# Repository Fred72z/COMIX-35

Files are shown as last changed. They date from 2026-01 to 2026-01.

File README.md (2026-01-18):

# COMIX-35 revision 1.2a

Le COMIX-35 est la réplique d'un ordinateur des années 1980, le COMX-35.
Il utilise le processeur COSMAC 1802 et dispose de 32K de mémoire vive et 3K de mémoir vidéo.

Cette version (1.2a) est une légère amélioration du COMIX-35 réalisé par "schlae".  
https://github.com/schlae/comix-35

Les améliorations sont : 
- le pcb est moins large (295mm) pour faciliter l'impression d'un boîtier
- les résistances ajustables sont verticales et plus petites
- le potentiomètre de volume est sur le côté G
- l'inter d'alimentation est vertical
- le connecteur d'extension est un modèle IDC 40 broches
- le circuit K7in est remplacé par un LM358 pour faciliter le chargement sans réglage de seuil.

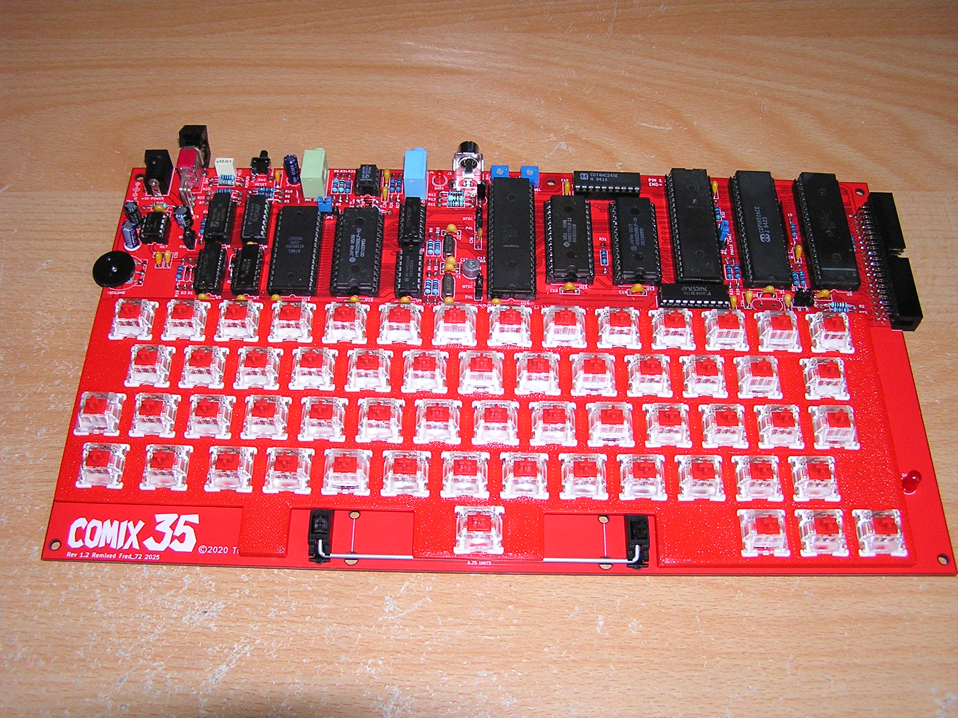
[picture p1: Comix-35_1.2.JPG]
Assemblage

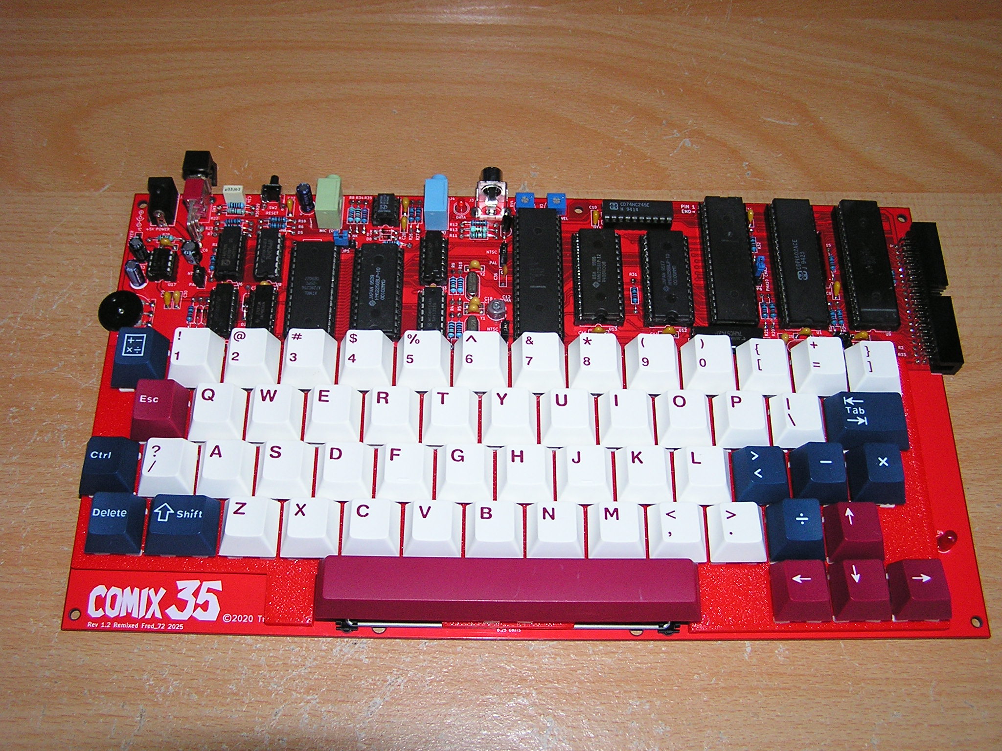
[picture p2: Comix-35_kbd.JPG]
Clavier


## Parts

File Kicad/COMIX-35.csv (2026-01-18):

Item | Qty | Reference(s) | Value | Digikey
1 | 21 | C1, C2, C3, C4, C5, C7, C8, C9, C10, C11, C14, C16, C17, C20, C21, C22, C25, C26, C28, C29, C30 | 0.1uF
2 | 1 | C6 | 100uF
3 | 1 | C12 | CHROMA | 2447-GKG30015-ND
4 | 6 | C13, C15, C18, C19, C23, C24 | 22pF
5 | 2 | C27, C32 | 47nF
7 | 2 | C31, C35 | 10uF
9 | 1 | C33 | 220uF
10 | 1 | C34 | 0.33uF
11 | 1 | C36 | 120pF
12 | 6 | D1, D2, D3, D5, D7, D8 | 1N4148
13 | 1 | D4 | POWER | Led D6mm
14 | 1 | D6 | DATA | Led D3mm
15 | 1 | J1 | Barrel_Jack | 5,5x2,1mm
16 | 1 | J2 | EXPANSION | IDC40 90°
17 | 1 | J3 | VIDEO | RCA PCB
18 | 1 | J4 | EAR | SJ1-353XN | Bleu
19 | 1 | J5 | Speaker
20 | 1 | J6 | MIC | SJ1-353XN | Vert
25 | 1 | M1 | Stabilisateur ‘ ‘ | 6u ou 7u
26 | 1 | Q1 | 2N3904
27 | 15 | R1, R3, R6, R14, R15, R16, R18, R19, R20, R21, R22, R26, R27, R31, R32 | 10K
28 | 2 | R2, R34 | 100K
29 | 3 | R4, R9, R23 | 1M
30 | 4 | R5, R10, R25, R29 | 1K
31 | 2 | R7, R33 | 2K2
 | 1 | R8 | 4K7
31 | 1 | R12 | 220
32 | 2 | R11, R28 | 10
33 | 1 | R13 | 75
34 | 1 | R17 | 10M
35 | 1 | R24 | 100K
36 | 1 | R30 | 100
 | 1 | R35 | 22K
37 | 1 | RN1 | 10K x 8 | SIP9
38 | 1 | RV2 | 10K | Pot plat 16x2 | Réglage volume
39 | 2 | RV3, RV4 | 10K | 3339P
40 | 1 | SW1 | POWER | T8020L
41 | 1 | SW2 | RESET | Tactile 9mm 90°
42 | 58 | SW3-SW60 |  | Cherry/Gateron
43 | 1 | U1 | CDP1802ACE
44 | 1 | U2 | 74HC574
45 | 2 | U3, U5 | 74HC74
46 | 1 | U4 | 74HCU04
47 | 1 | U6 | 74HC10
48 | 1 | U7 | 74HC86
49 | 1 | U8 | 74HC14
50 | 1 | U9 | CDP1871
51 | 1 | U10 | CDP1869
52 | 1 | U11 | 74HC245
53 | 3 | U12, U13, U16 | AS6C62256
54 | 1 | U14 | CDP1870
55 | 1 | U15 | 28C256
56 | 1 | U17 | LM386
56 | 1 | U18 | LM358
57 | 1 | Y1 | 17.738MHz
58 | 1 | Y2 | 11.2896MHz

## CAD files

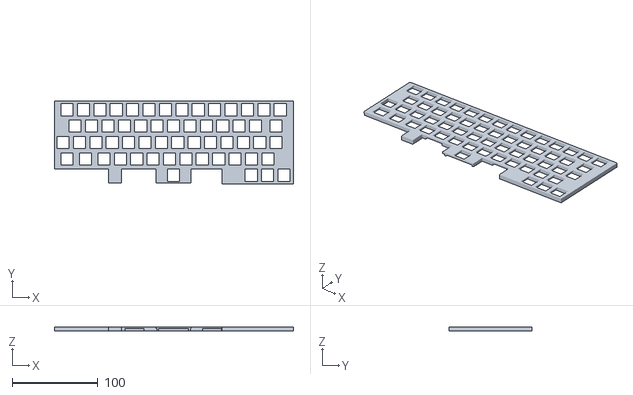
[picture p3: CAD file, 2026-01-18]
KBD/plaque_kbd.stl
278.0 x 96.0 x 5.00

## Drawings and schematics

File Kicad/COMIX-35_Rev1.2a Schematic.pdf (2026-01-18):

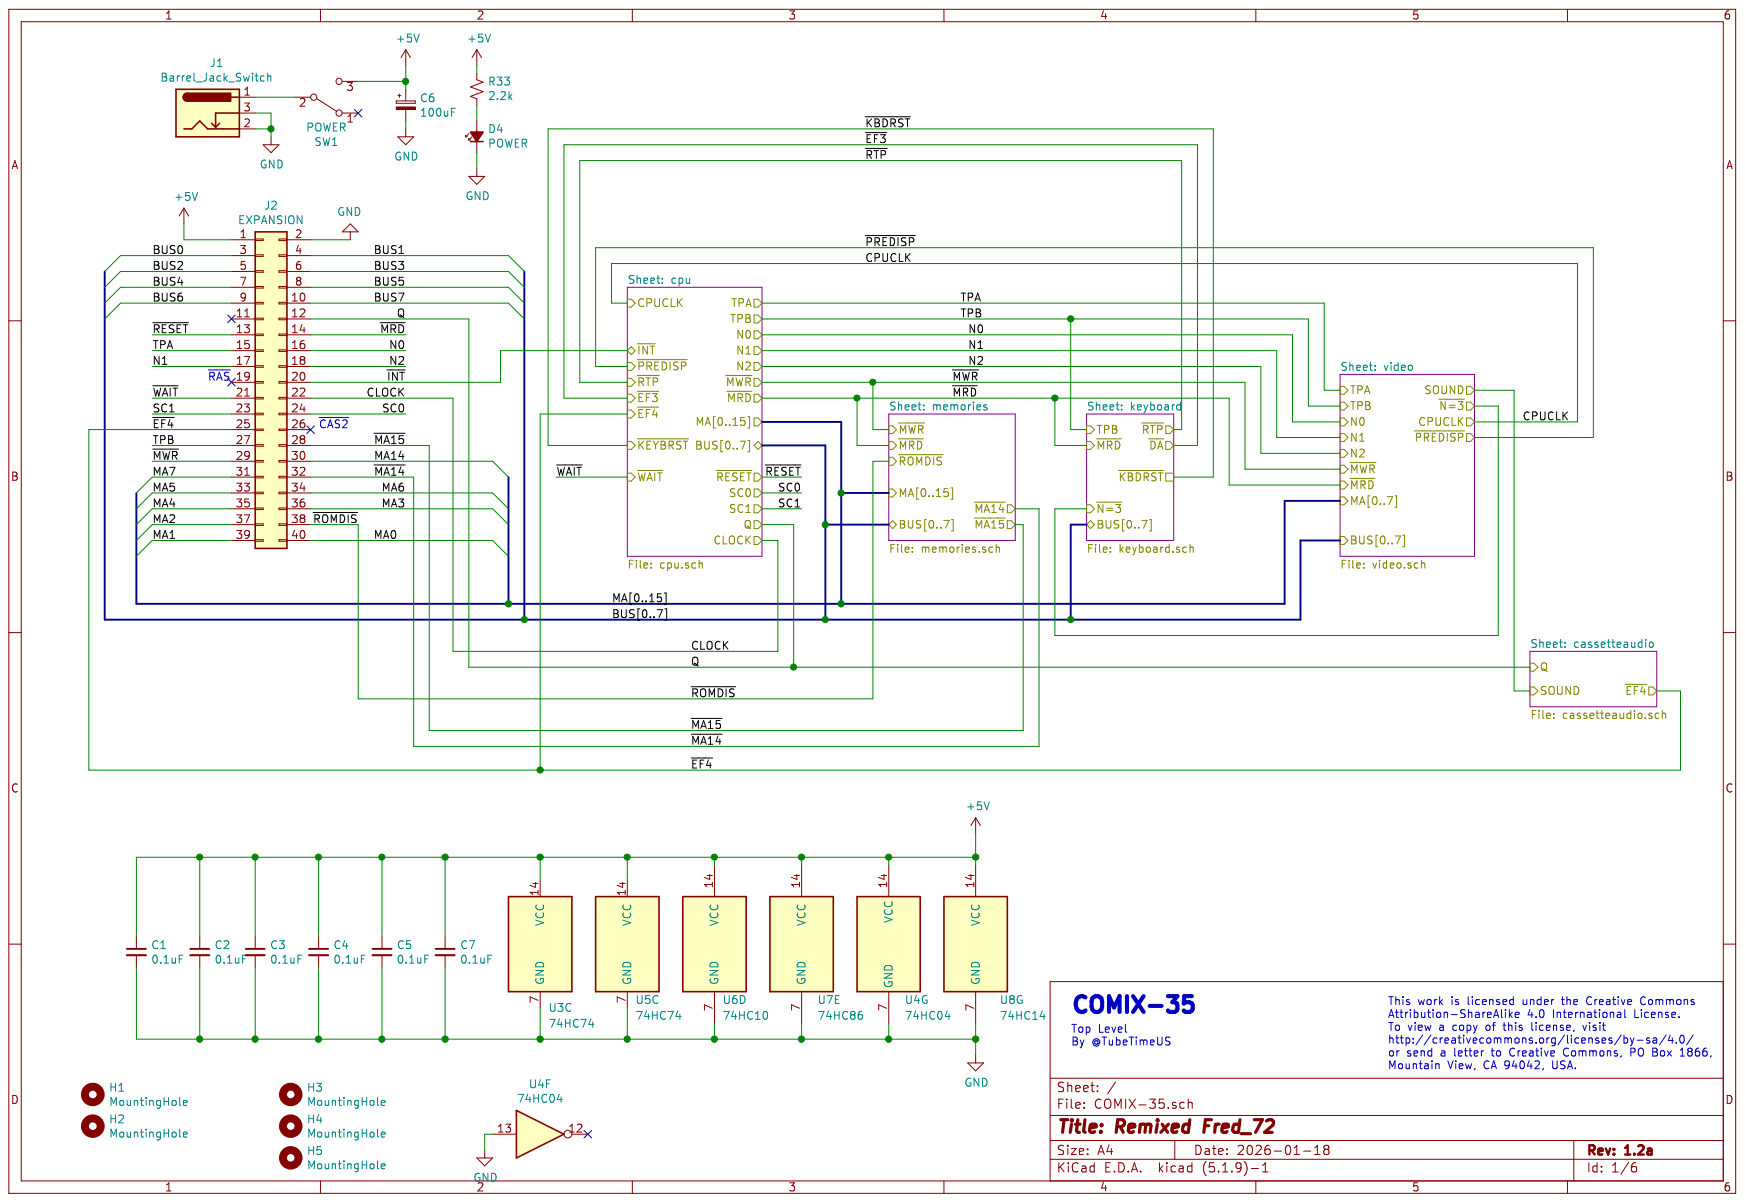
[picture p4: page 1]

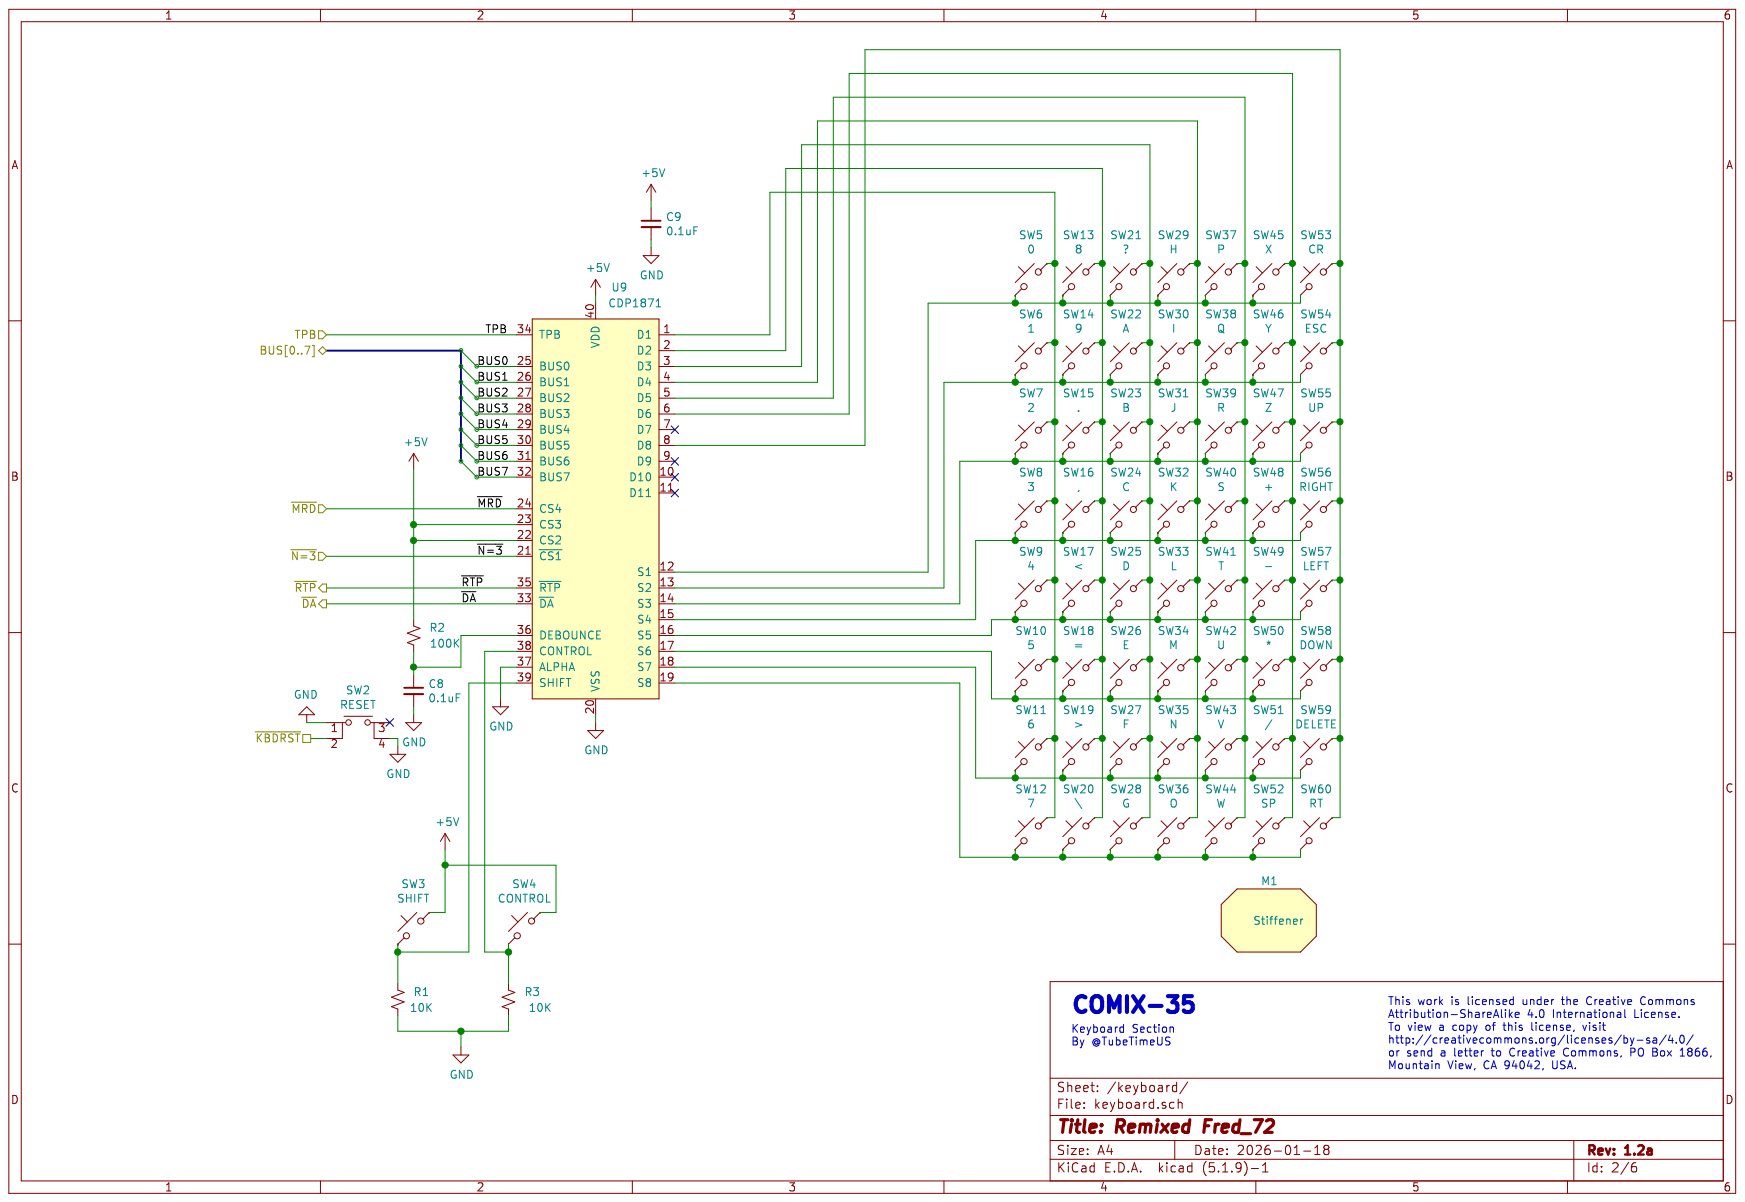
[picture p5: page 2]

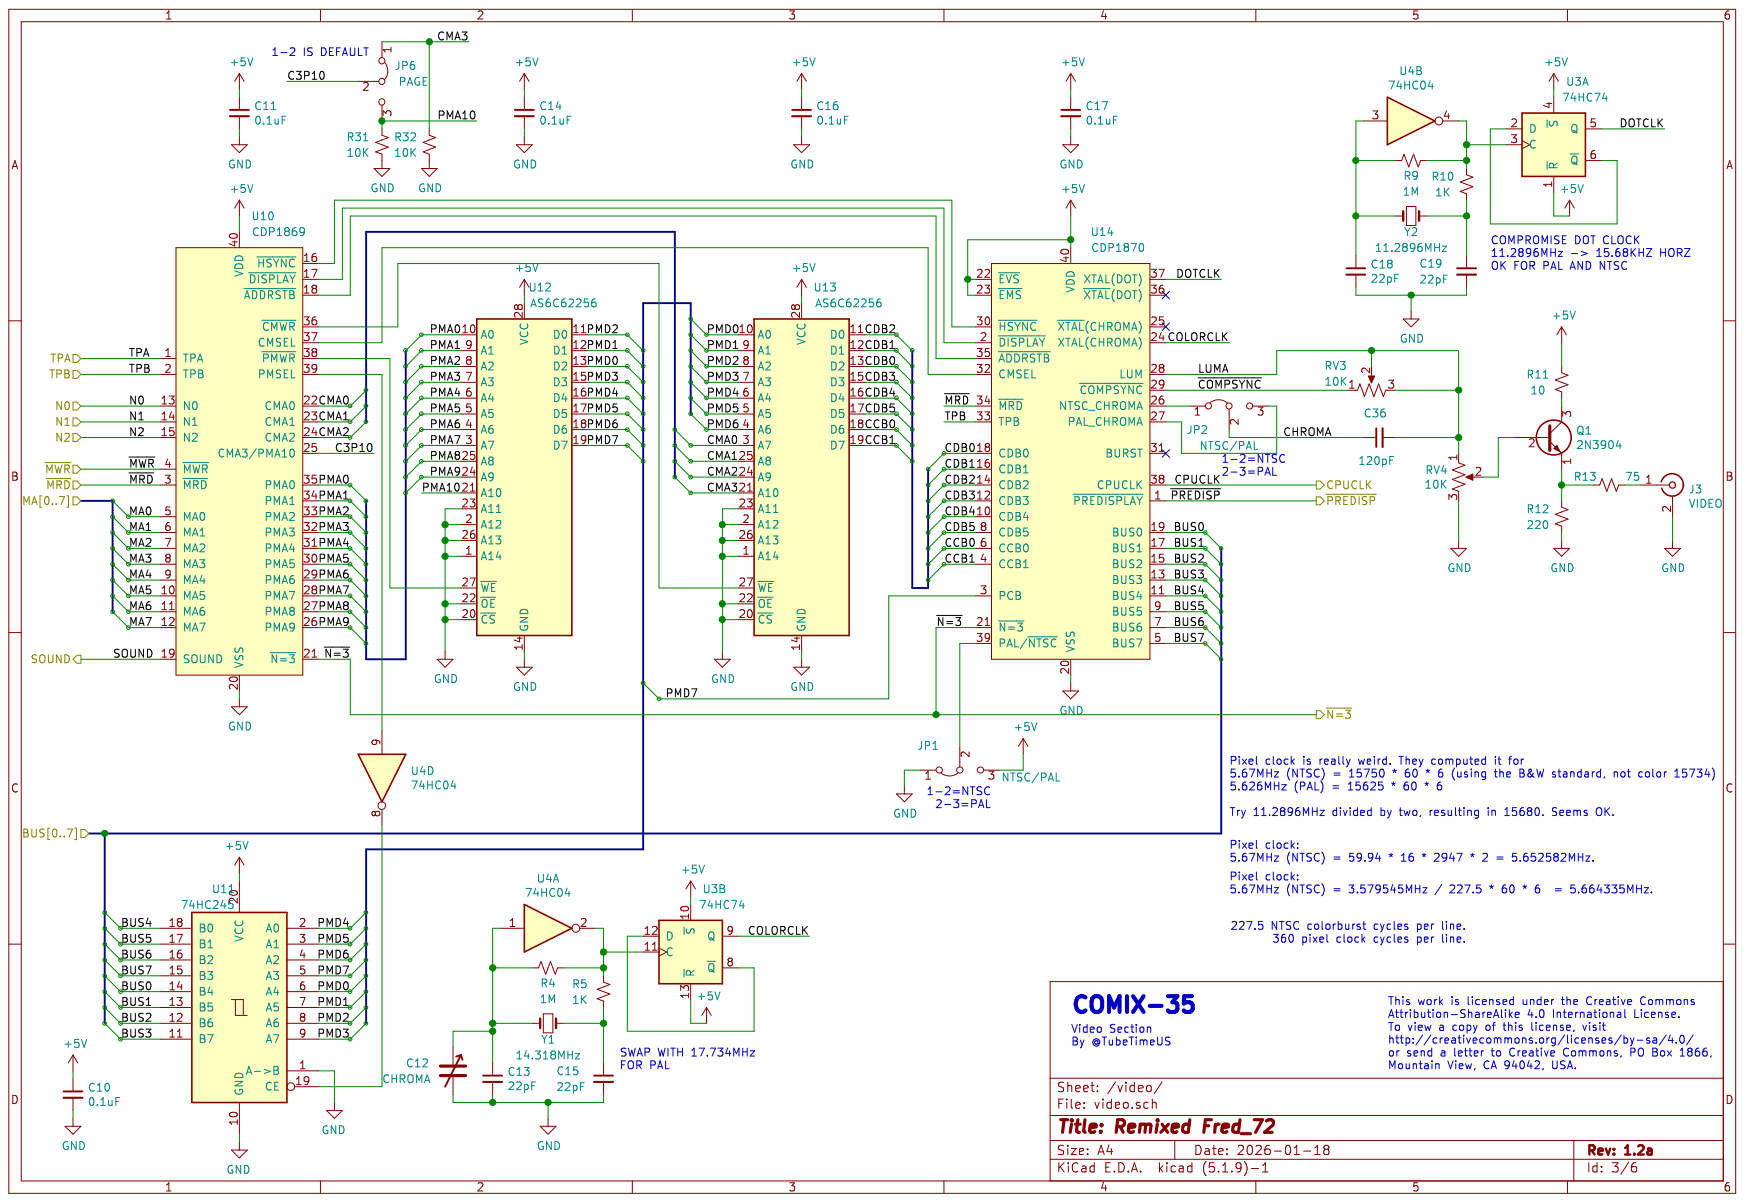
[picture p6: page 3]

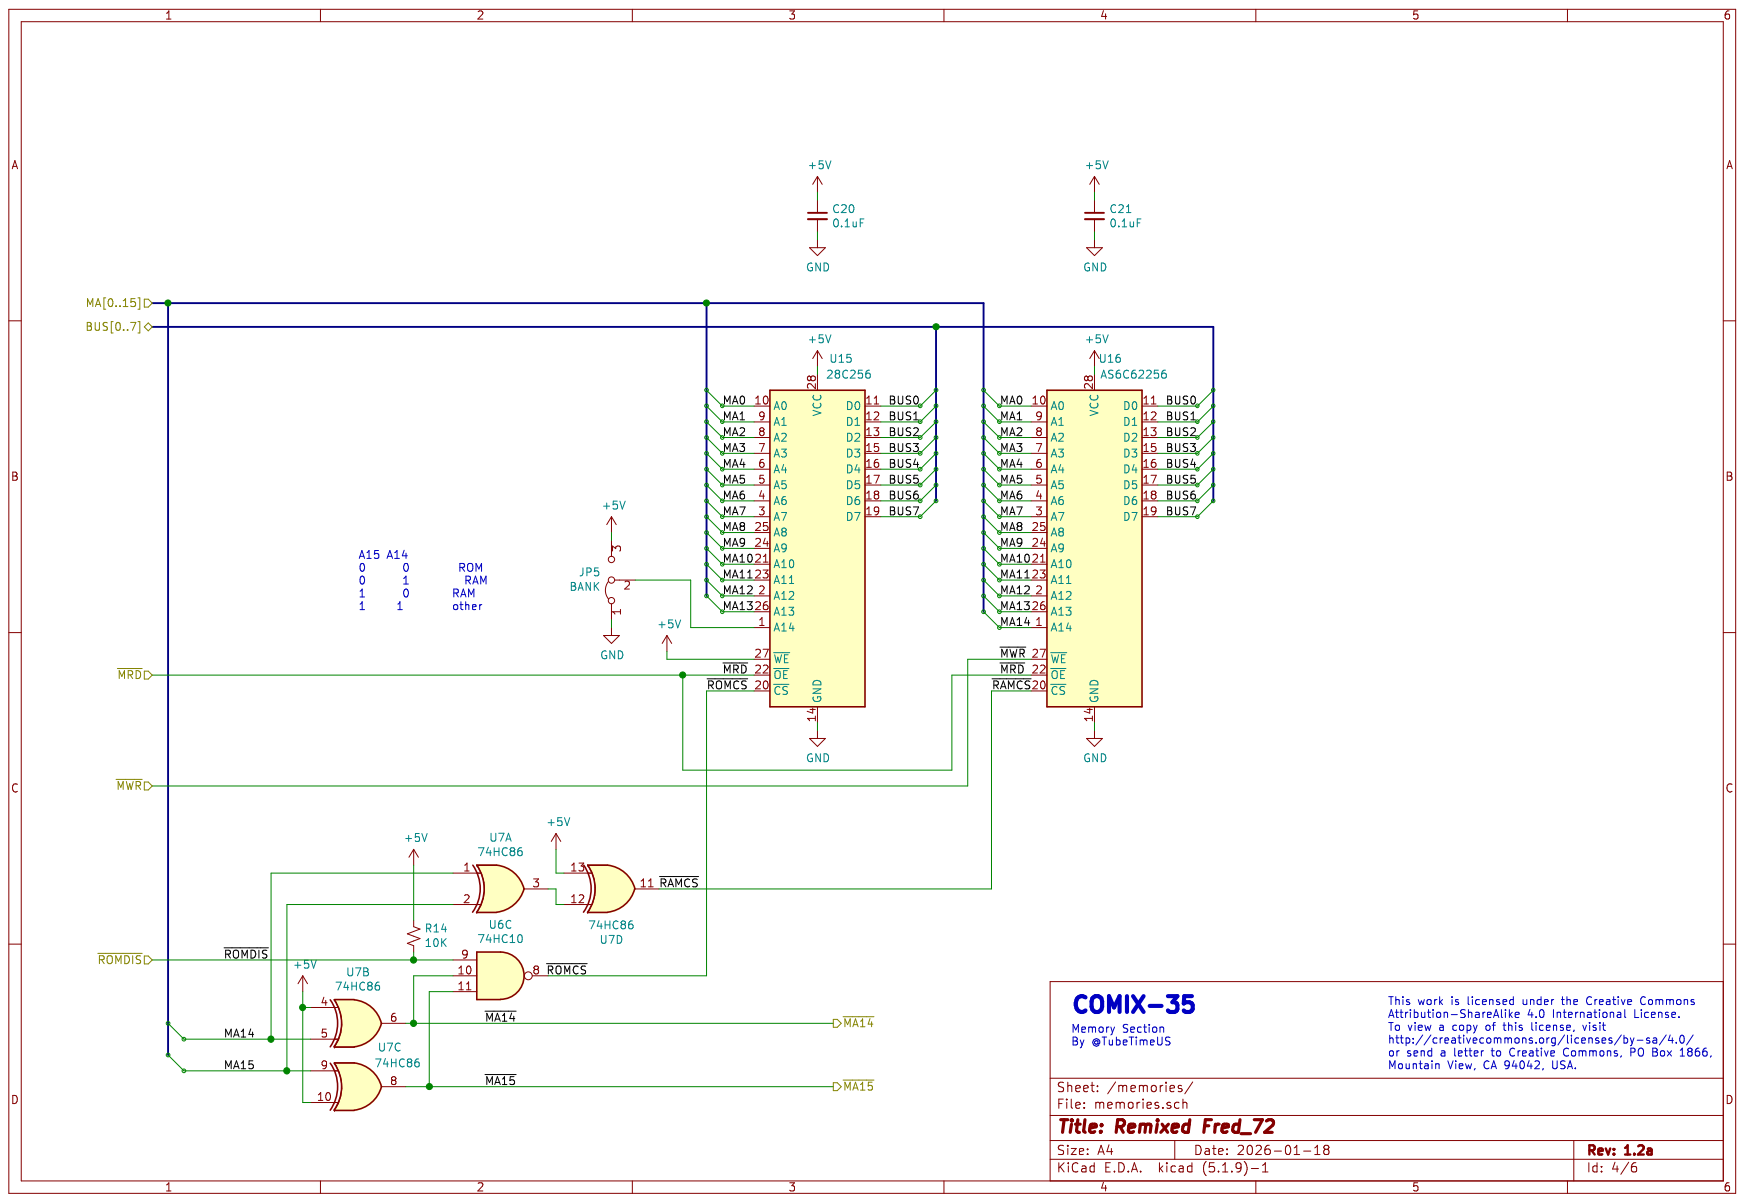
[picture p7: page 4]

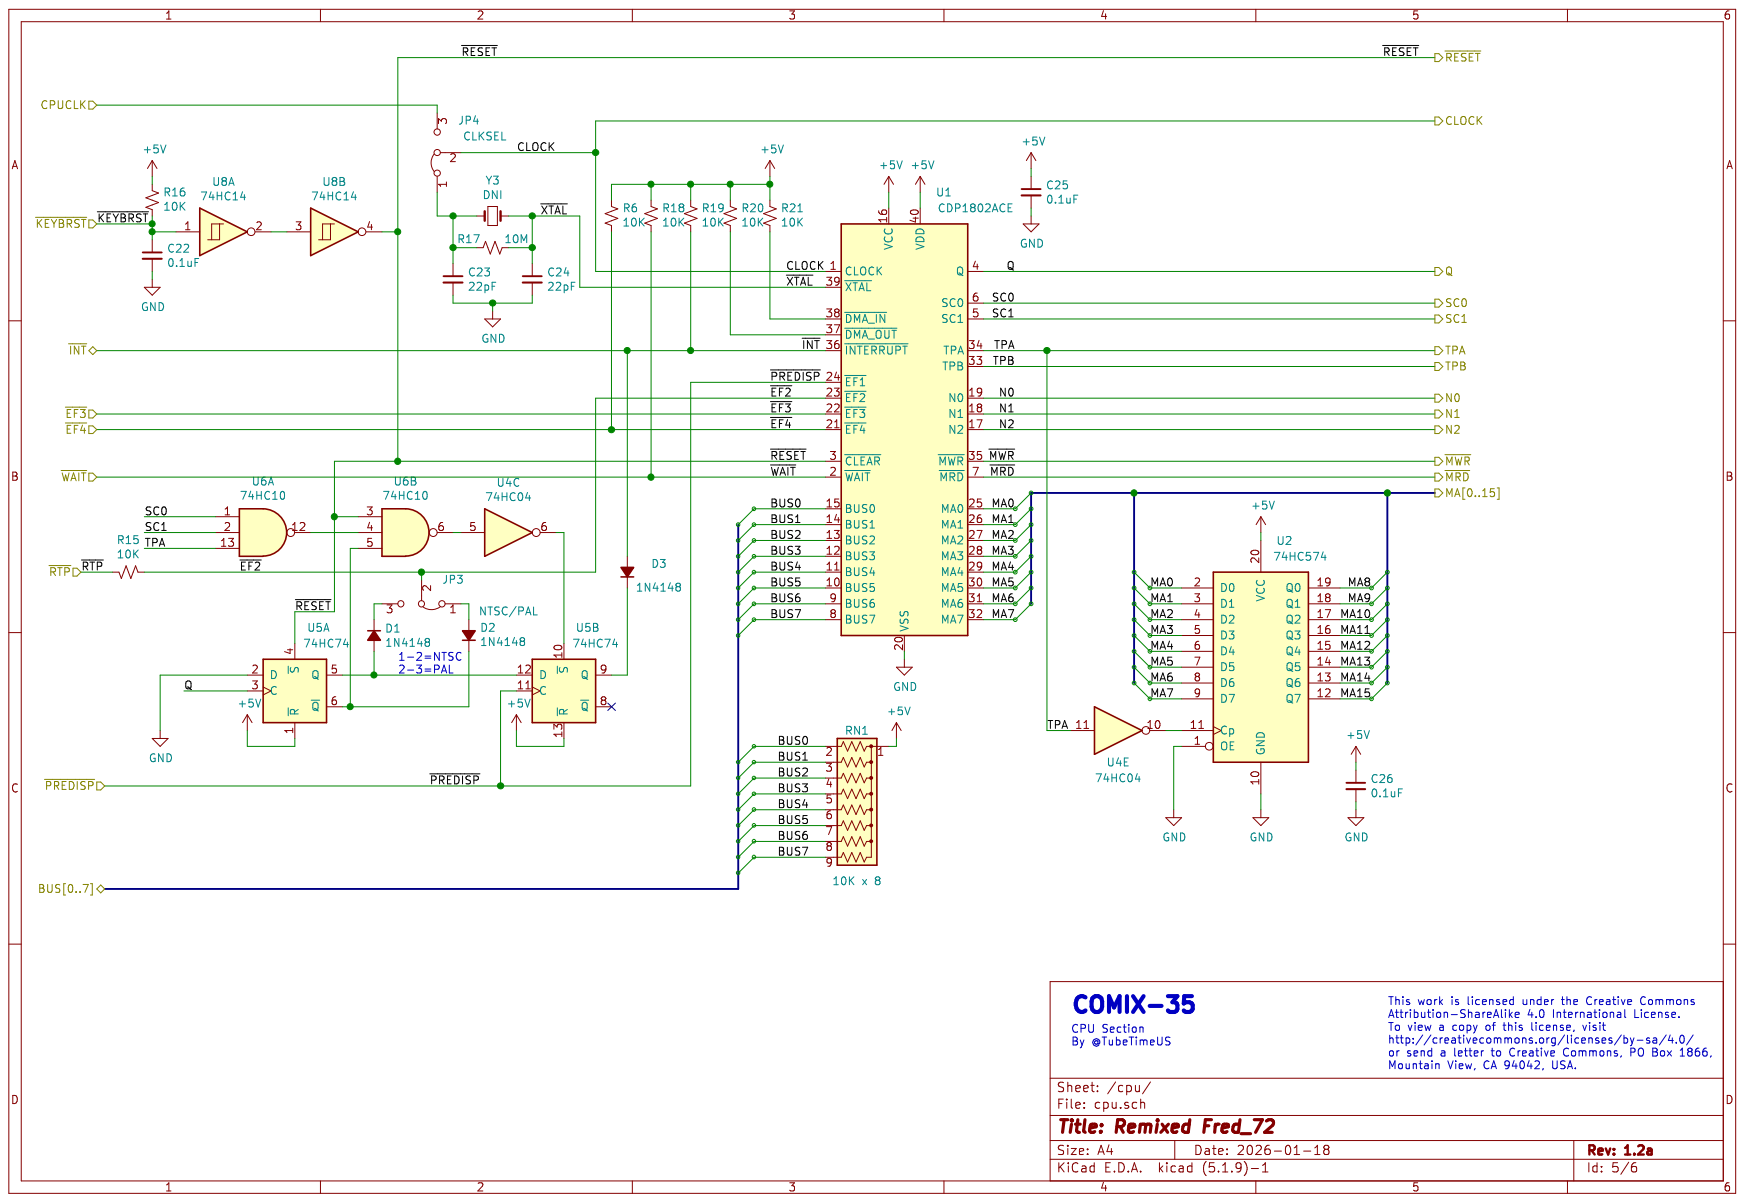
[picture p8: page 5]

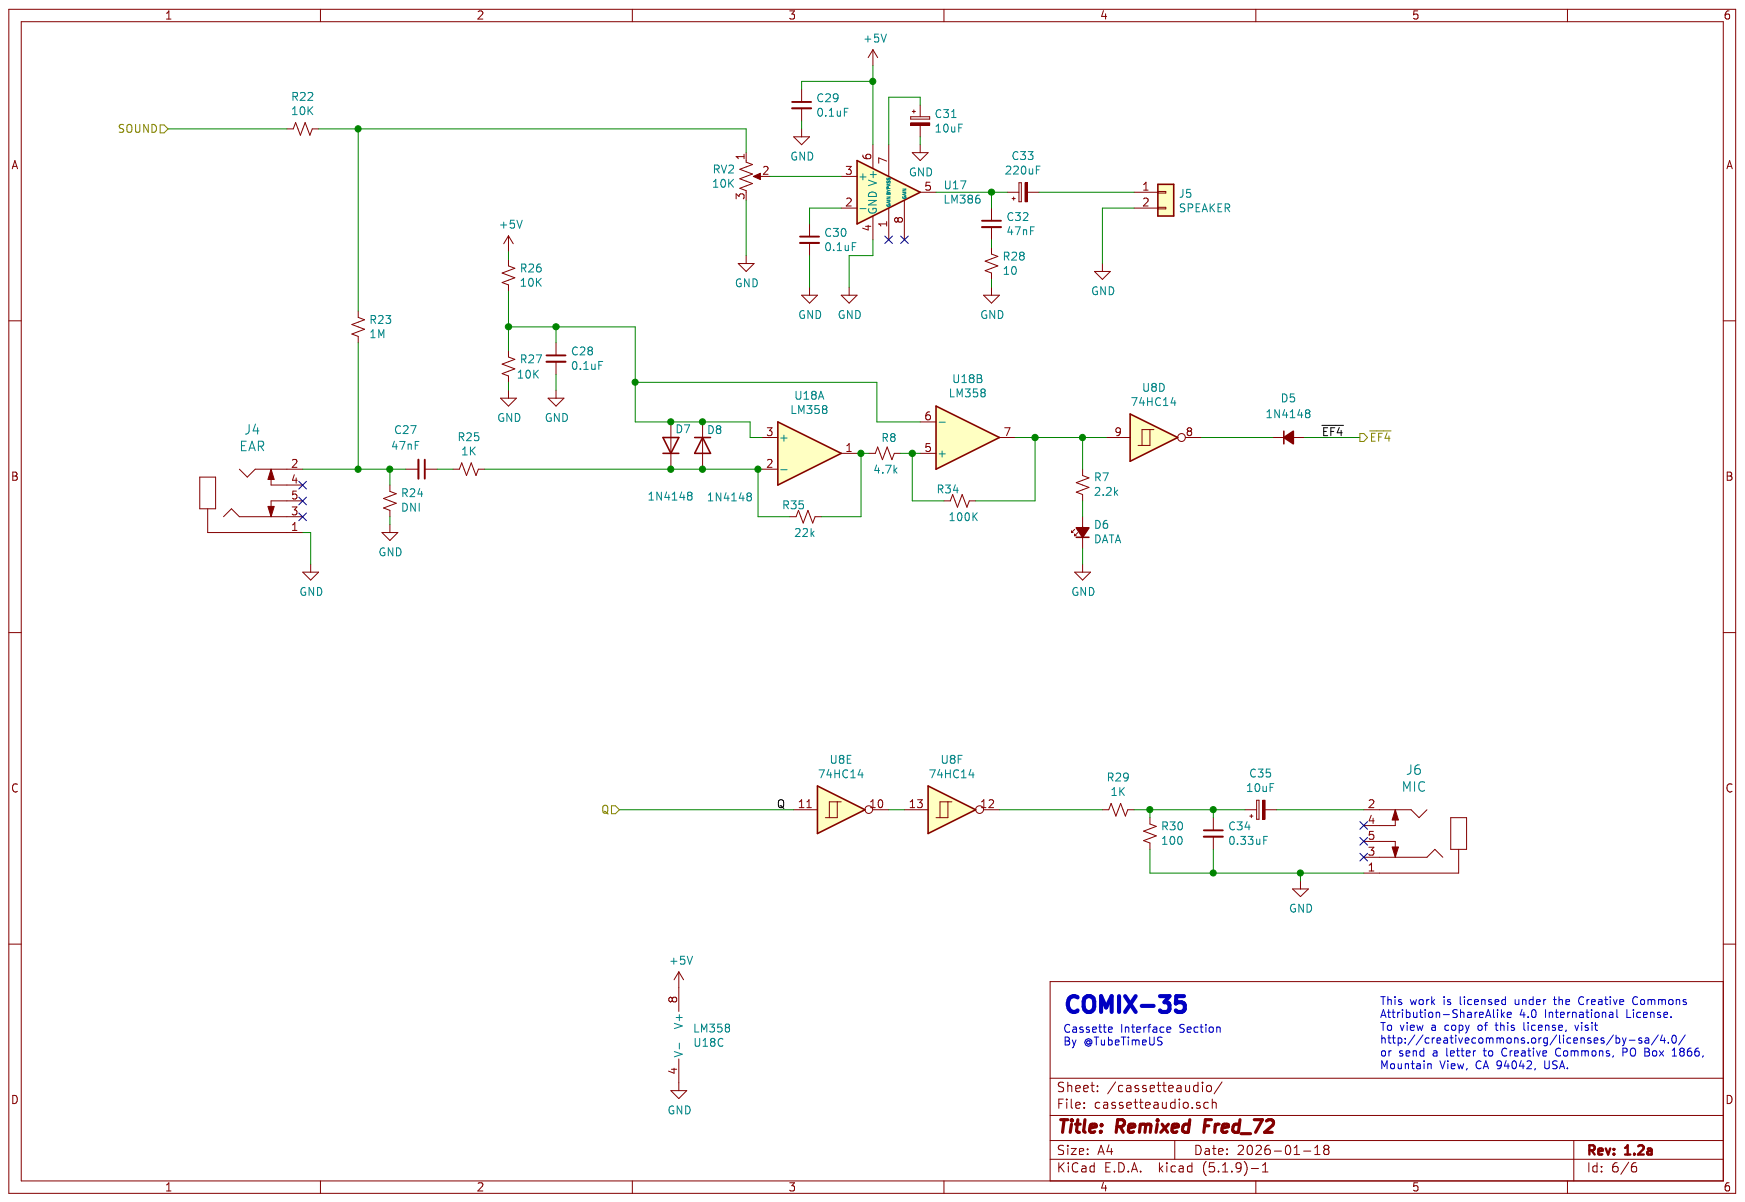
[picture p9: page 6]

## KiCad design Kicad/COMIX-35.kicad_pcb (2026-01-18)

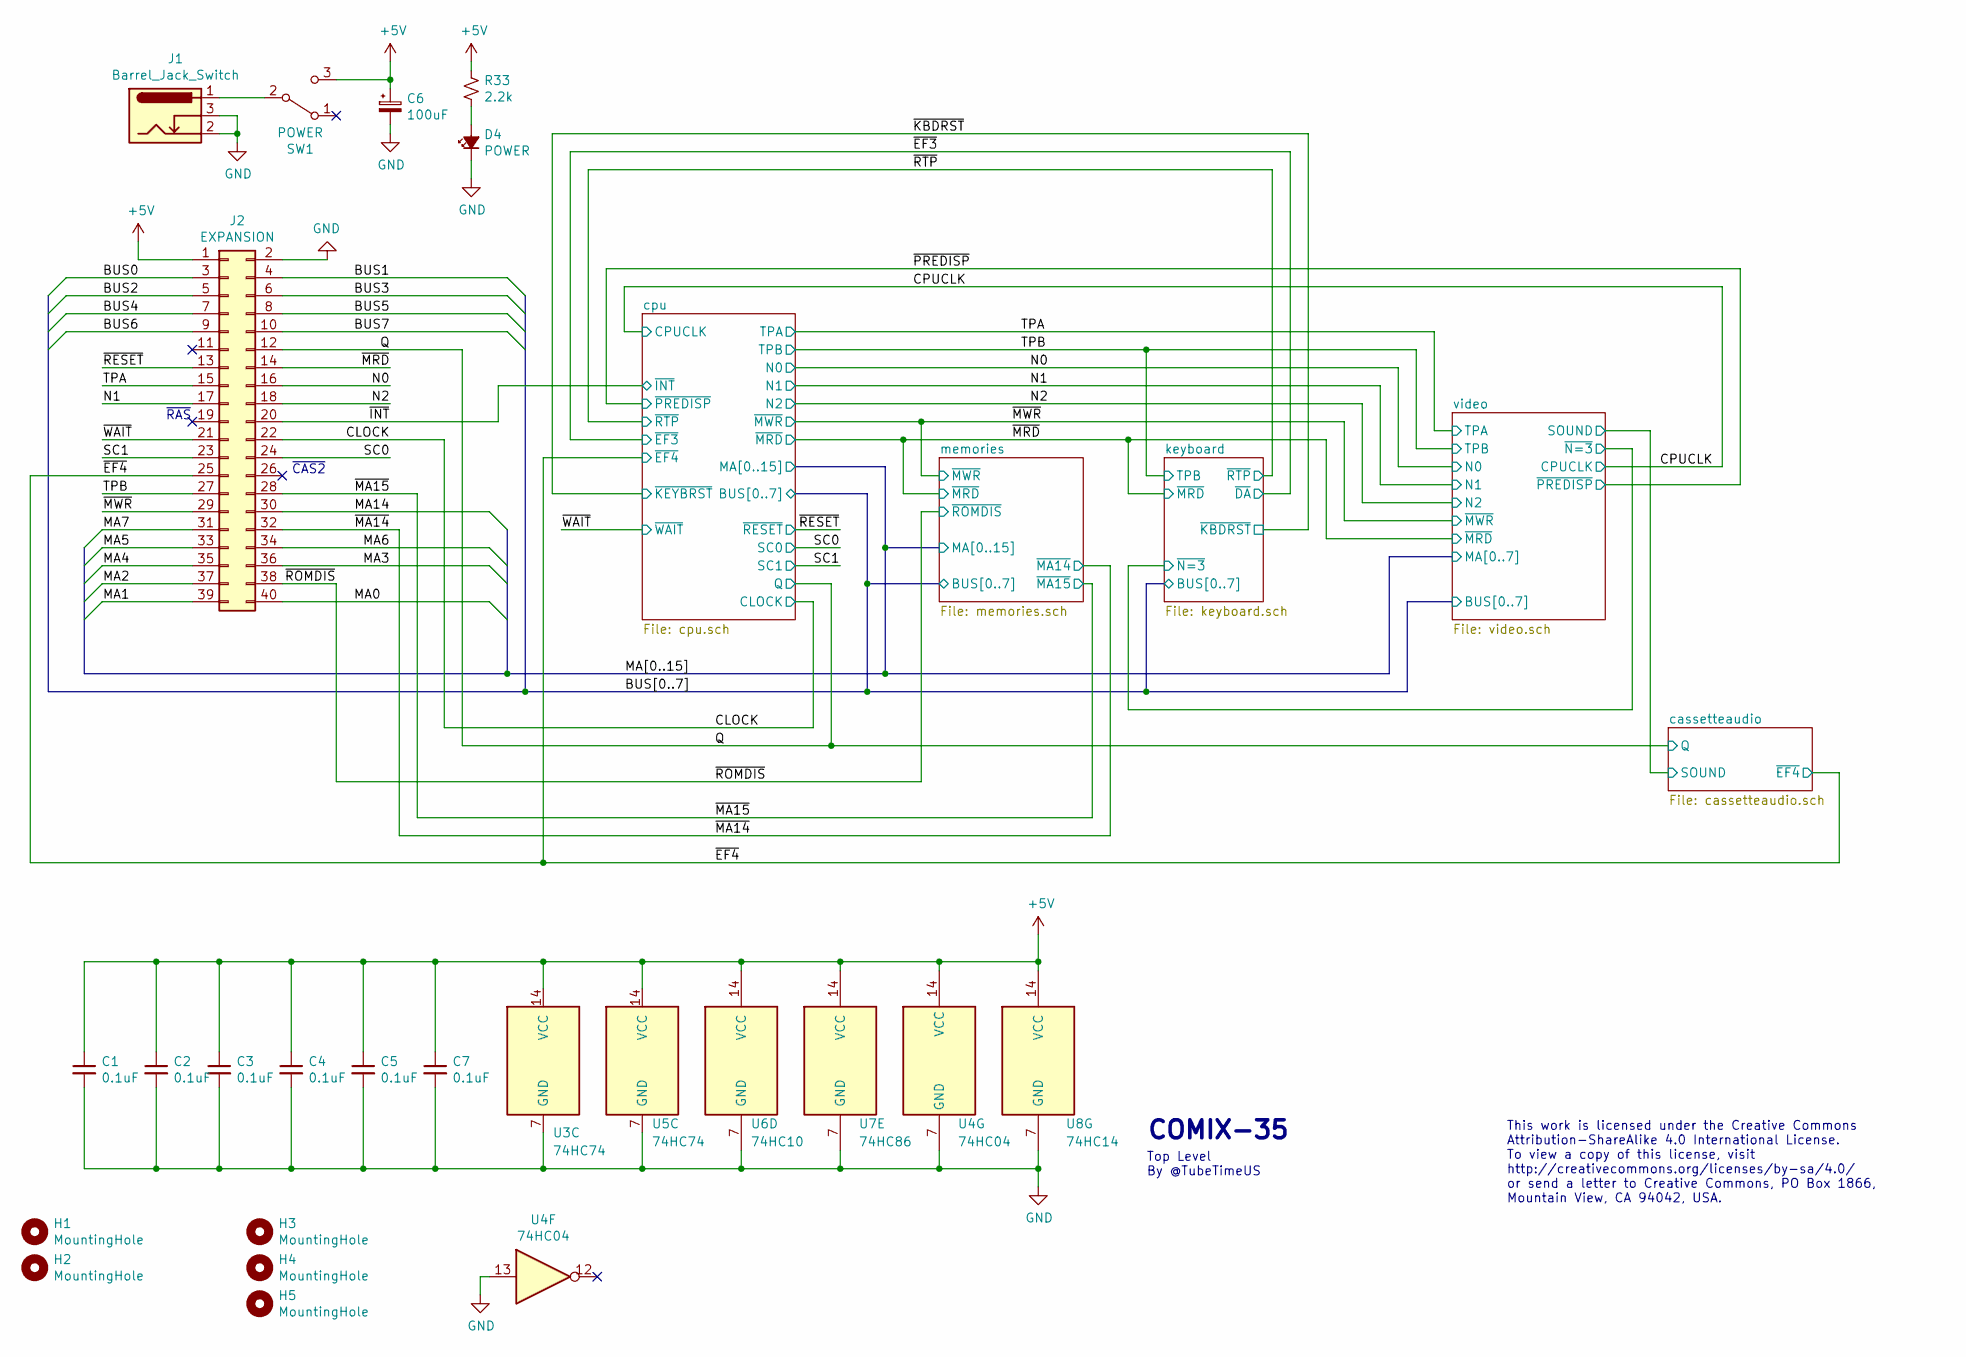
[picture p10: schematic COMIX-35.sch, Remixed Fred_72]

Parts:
C1, C2, C3, C4, C5, C7: 0.1uF; CAPAC200; Mouser 581-SA105E104M
C6: 100uF; CAPAE200P500X1100; Mouser 667-ECA-1CM101I
D4: POWER; LED_D5.0mm; Mouser 859-LTL-4213
H1, H2, H3, H4, H5: MountingHole; MountingHole_3.2mm_M3_DIN965
J1: Barrel_Jack_Switch; CUI_PJ-002B; Mouser 490-PJ-002B
J2: EXPANSION; IDC-Header_2x20_P2.54mm_Horizontal
R33: 2.2k; RESA500; Mouser 603-CFR-25JR-52220R
SW1: POWER; T8020L; Mouser 633-CS12ANW03
U3, U5: 74HC74; DIP-14_W7.62mm; Mouser 595-SN74HC74N
U4: 74HC04; DIP-14_W7.62mm; Mouser 595-SN74HCU04N
U6: 74HC10; DIP-14_W7.62mm; Mouser 595-SN74HC10N
U7: 74HC86; DIP-14_W7.62mm; Mouser 595-SN74HC86N
U8: 74HC14; DIP-14_W7.62mm; Mouser 595-SN74HC14N

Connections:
+5V: C1.1, C2.1, C3.1, C4.1, C5.1, C6.1, C7.1, J2.1, R33.2, SW1.3 (C), U3.14 (VCC), U4.14 (VCC), U5.14 (VCC), U6.14 (VCC), U7.14 (VCC), U8.14 (VCC); also elsewhere on the board
/BUS0: J2.3; also elsewhere on the board
/BUS1: J2.4; also elsewhere on the board
/BUS2: J2.5; also elsewhere on the board
/BUS3: J2.6; also elsewhere on the board
/BUS4: J2.7; also elsewhere on the board
/BUS5: J2.8; also elsewhere on the board
/BUS6: J2.9; also elsewhere on the board
/BUS7: J2.10; also elsewhere on the board
/CLOCK: J2.22; also elsewhere on the board
/MA0: J2.40; also elsewhere on the board
/MA1: J2.39; also elsewhere on the board
/MA2: J2.37; also elsewhere on the board
/MA3: J2.36; also elsewhere on the board
/MA4: J2.35; also elsewhere on the board
/MA5: J2.33; also elsewhere on the board
/MA6: J2.34; also elsewhere on the board
/MA7: J2.31; also elsewhere on the board
/MA14: J2.30; also elsewhere on the board
/N0: J2.16; also elsewhere on the board
/N1: J2.17; also elsewhere on the board
/N2: J2.18; also elsewhere on the board
/Q: J2.12; also elsewhere on the board
/SC0: J2.24; also elsewhere on the board
/SC1: J2.23; also elsewhere on the board
/TPA: J2.15; also elsewhere on the board
/TPB: J2.27; also elsewhere on the board
/~EF4: J2.25; also elsewhere on the board
/~INT: J2.20; also elsewhere on the board
/~MA14: J2.32; also elsewhere on the board
/~MA15: J2.28; also elsewhere on the board
/~MRD: J2.14; also elsewhere on the board
/~MWR: J2.29; also elsewhere on the board
/~RESET: J2.13; also elsewhere on the board
/~ROMDIS: J2.38; also elsewhere on the board
/~WAIT: J2.21; also elsewhere on the board
GND: C1.2, C2.2, C3.2, C4.2, C5.2, C6.2, C7.2, D4.1 (K), J1.2, J1.3, J2.2, U3.7 (GND), U4.7 (GND), U4.13, U5.7 (GND), U6.7 (GND), U7.7 (GND), U8.7 (GND); also elsewhere on the board
unnamed: D4.2 (A), R33.1
unnamed: J1.1, SW1.2 (B)

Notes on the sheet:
~RAS
~CAS2
This work is licensed under the Creative Commons Attribution-ShareAlike 4.0 International License. To view a copy of this license, visit http://creativecommons.org/licenses/by-sa/4.0/ or send a letter to Creative Commons, PO Box 1866, Mountain View, CA 94042, USA.
COMIX-35
Top Level By @TubeTimeUS

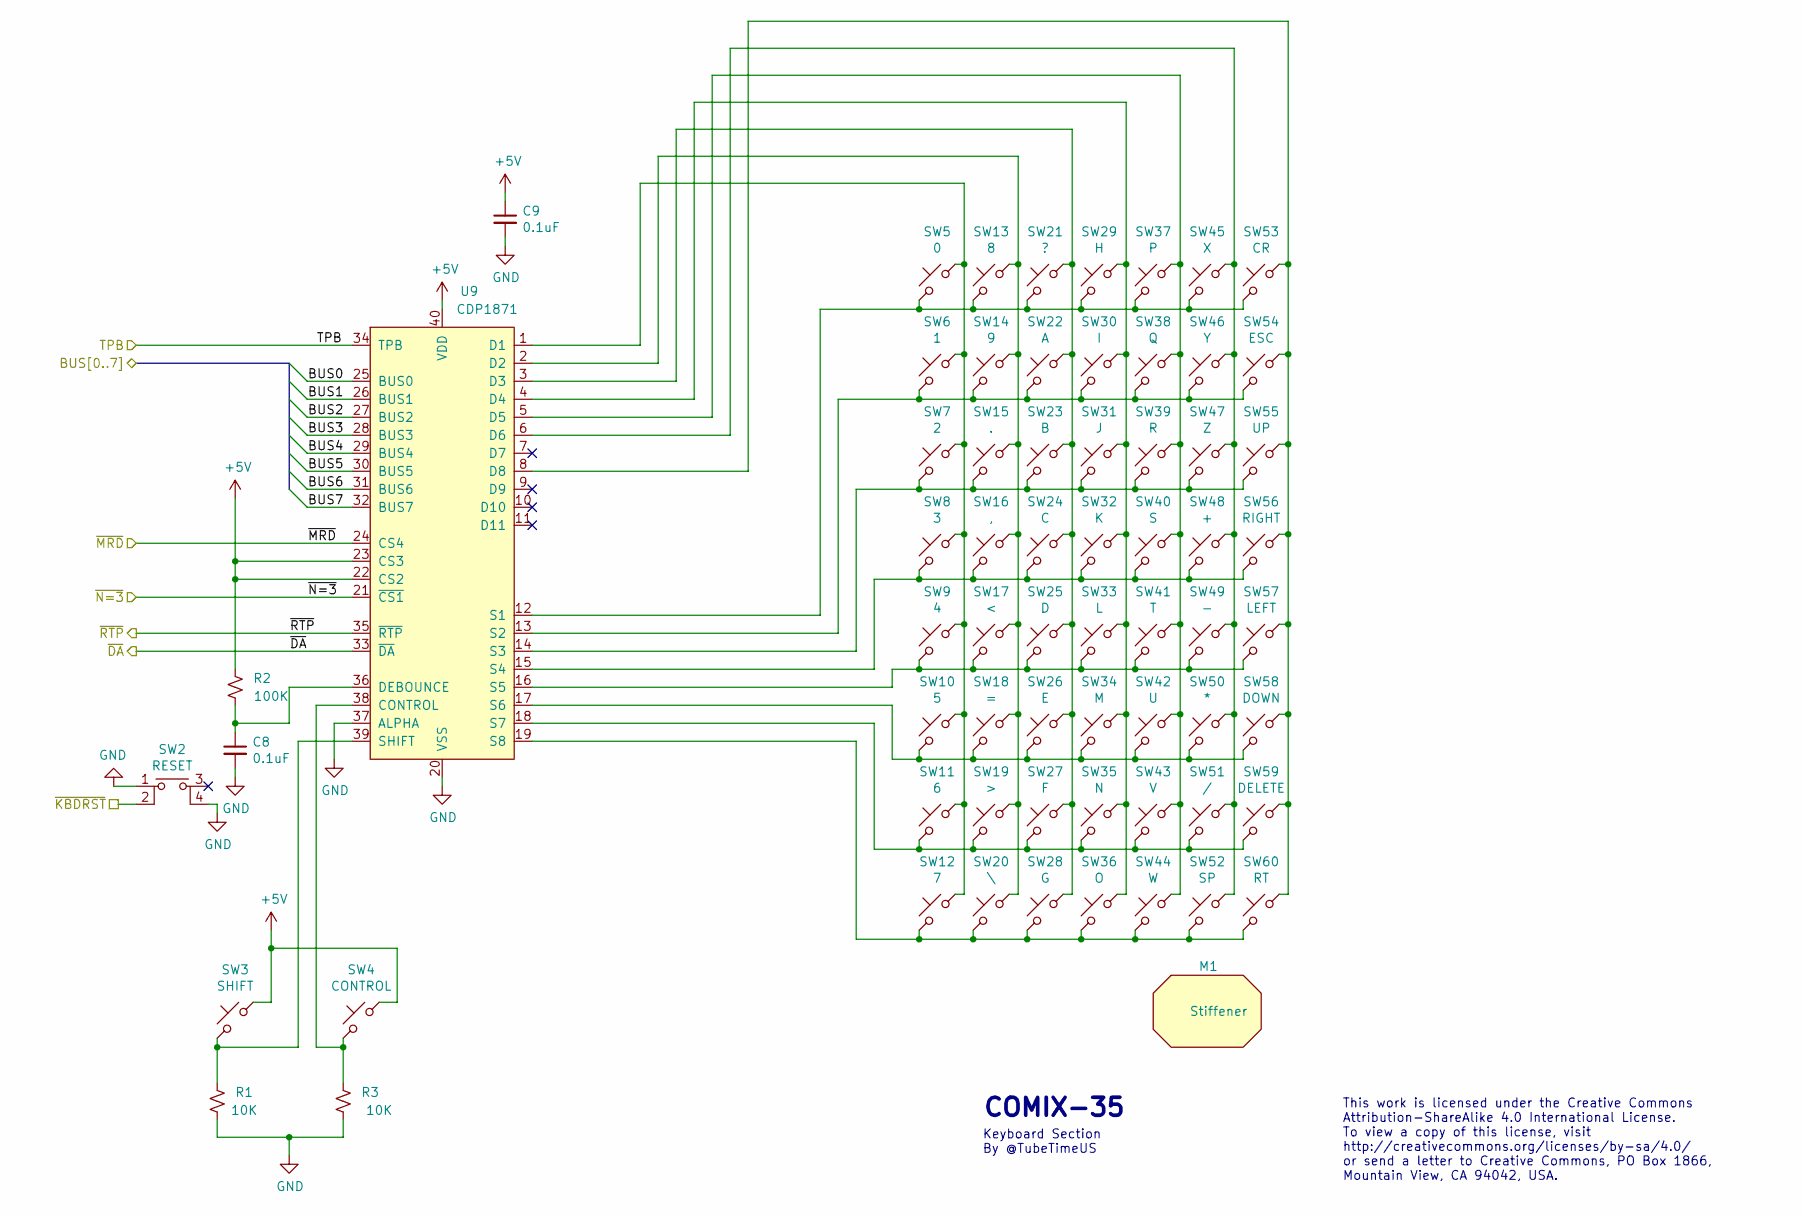
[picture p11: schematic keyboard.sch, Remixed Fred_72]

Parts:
C8, C9: 0.1uF; CAPAC200; Mouser 581-SA105E104M
M1: Stiffener; CHERRY_ST2; Mouser 540-0G990743
R1, R3: 10K; RESA500; Mouser 603-CFR-25JB-52-10K
R2: 100K; RESA500; Mouser 603-CFR-25JB-52-100K
SW2: RESET; SW_Tactile_SPST_Angled_PTS645Vx58-2LFS; Mouser 612-TL1105B
SW3: SHIFT; CHERRY_MX_125; Mouser 540-MX1A-11NW
SW4: CONTROL; CHERRY_MX; Mouser 540-MX1A-11NW
SW5: 0; CHERRY_MX; Mouser 540-MX1A-11NW
SW6: 1; CHERRY_MX; Mouser 540-MX1A-11NW
SW7: 2; CHERRY_MX; Mouser 540-MX1A-11NW
SW8: 3; CHERRY_MX; Mouser 540-MX1A-11NW
SW9: 4; CHERRY_MX; Mouser 540-MX1A-11NW
SW10: 5; CHERRY_MX; Mouser 540-MX1A-11NW
SW11: 6; CHERRY_MX; Mouser 540-MX1A-11NW
SW12: 7; CHERRY_MX; Mouser 540-MX1A-11NW
SW13: 8; CHERRY_MX; Mouser 540-MX1A-11NW
SW14: 9; CHERRY_MX; Mouser 540-MX1A-11NW
SW15: .; CHERRY_MX; Mouser 540-MX1A-11NW
SW16: ,; CHERRY_MX; Mouser 540-MX1A-11NW
SW17: <; CHERRY_MX; Mouser 540-MX1A-11NW
SW18: =; CHERRY_MX; Mouser 540-MX1A-11NW
SW19: >; CHERRY_MX; Mouser 540-MX1A-11NW
SW20: \\; CHERRY_MX; Mouser 540-MX1A-11NW
SW21: ?; CHERRY_MX; Mouser 540-MX1A-11NW
SW22: A; CHERRY_MX; Mouser 540-MX1A-11NW
SW23: B; CHERRY_MX; Mouser 540-MX1A-11NW
SW24: C; CHERRY_MX; Mouser 540-MX1A-11NW
SW25: D; CHERRY_MX; Mouser 540-MX1A-11NW
SW26: E; CHERRY_MX; Mouser 540-MX1A-11NW
SW27: F; CHERRY_MX; Mouser 540-MX1A-11NW
SW28: G; CHERRY_MX; Mouser 540-MX1A-11NW
SW29: H; CHERRY_MX; Mouser 540-MX1A-11NW
SW30: I; CHERRY_MX; Mouser 540-MX1A-11NW
SW31: J; CHERRY_MX; Mouser 540-MX1A-11NW
SW32: K; CHERRY_MX; Mouser 540-MX1A-11NW
SW33: L; CHERRY_MX; Mouser 540-MX1A-11NW
SW34: M; CHERRY_MX; Mouser 540-MX1A-11NW
SW35: N; CHERRY_MX; Mouser 540-MX1A-11NW
SW36: O; CHERRY_MX; Mouser 540-MX1A-11NW
SW37: P; CHERRY_MX; Mouser 540-MX1A-11NW
SW38: Q; CHERRY_MX; Mouser 540-MX1A-11NW
SW39: R; CHERRY_MX; Mouser 540-MX1A-11NW
SW40: S; CHERRY_MX; Mouser 540-MX1A-11NW
SW41: T; CHERRY_MX; Mouser 540-MX1A-11NW
SW42: U; CHERRY_MX; Mouser 540-MX1A-11NW
SW43: V; CHERRY_MX; Mouser 540-MX1A-11NW
SW44: W; CHERRY_MX; Mouser 540-MX1A-11NW
SW45: X; CHERRY_MX; Mouser 540-MX1A-11NW
SW46: Y; CHERRY_MX; Mouser 540-MX1A-11NW
SW47: Z; CHERRY_MX; Mouser 540-MX1A-11NW
SW48: +; CHERRY_MX; Mouser 540-MX1A-11NW
SW49: -; CHERRY_MX; Mouser 540-MX1A-11NW
SW50: *; CHERRY_MX; Mouser 540-MX1A-11NW
SW51: /; CHERRY_MX; Mouser 540-MX1A-11NW
SW52: SP; CHERRY_MX_625; Mouser 540-MX1A-11NW
SW53: CR; CHERRY_MX_150; Mouser 540-MX1A-11NW
SW54: ESC; CHERRY_MX; Mouser 540-MX1A-11NW
SW55: UP; CHERRY_MX; Mouser 540-MX1A-11NW
SW56: RIGHT; CHERRY_MX; Mouser 540-MX1A-11NW
SW57: LEFT; CHERRY_MX; Mouser 540-MX1A-11NW
SW58: DOWN; CHERRY_MX; Mouser 540-MX1A-11NW
SW59: DELETE; CHERRY_MX; Mouser 540-MX1A-11NW
SW60: RT; CHERRY_MX; Mouser 540-MX1A-11NW
U9: CDP1871; DIP-40_W15.24mm

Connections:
+5V: C9.1, R2.1, SW3.1, SW4.1, U9.22 (CS2), U9.23 (CS3), U9.40 (VDD); also elsewhere on the board
/BUS0: U9.25 (BUS0); also elsewhere on the board
/BUS1: U9.26 (BUS1); also elsewhere on the board
/BUS2: U9.27 (BUS2); also elsewhere on the board
/BUS3: U9.28 (BUS3); also elsewhere on the board
/BUS4: U9.29 (BUS4); also elsewhere on the board
/BUS5: U9.30 (BUS5); also elsewhere on the board
/BUS6: U9.31 (BUS6); also elsewhere on the board
/BUS7: U9.32 (BUS7); also elsewhere on the board
/TPB: U9.34 (TPB); also elsewhere on the board
/keyboard/~N=3: U9.21 (~CS1); also elsewhere on the board
/~EF3: U9.33 (~DA); also elsewhere on the board
/~KBDRST: SW2.2; also elsewhere on the board
/~MRD: U9.24 (CS4); also elsewhere on the board
/~RTP: U9.35 (~RTP); also elsewhere on the board
GND: C8.2, C9.2, R1.2, R3.2, SW2.1, SW2.4, U9.20 (VSS), U9.37 (ALPHA); also elsewhere on the board
unnamed: C8.1, R2.2, U9.36 (DEBOUNCE)
unnamed: R1.1, SW3.2, U9.39 (SHIFT)
unnamed: R3.1, SW4.2, U9.38 (CONTROL)
unnamed: SW5.1, SW6.1, SW7.1, SW8.1, SW9.1, SW10.1, SW11.1, SW12.1, U9.1 (D1)
unnamed: SW10.2, SW18.2, SW26.2, SW34.2, SW42.2, SW50.2, SW58.2, U9.17 (S6)
unnamed: SW11.2, SW19.2, SW27.2, SW35.2, SW43.2, SW51.2, SW59.2, U9.18 (S7)
unnamed: SW12.2, SW20.2, SW28.2, SW36.2, SW44.2, SW52.2, SW60.2, U9.19 (S8)
unnamed: SW13.1, SW14.1, SW15.1, SW16.1, SW17.1, SW18.1, SW19.1, SW20.1, U9.2 (D2)
unnamed: SW5.2, SW13.2, SW21.2, SW29.2, SW37.2, SW45.2, SW53.2, U9.12 (S1)
unnamed: SW6.2, SW14.2, SW22.2, SW30.2, SW38.2, SW46.2, SW54.2, U9.13 (S2)
unnamed: SW7.2, SW15.2, SW23.2, SW31.2, SW39.2, SW47.2, SW55.2, U9.14 (S3)
unnamed: SW8.2, SW16.2, SW24.2, SW32.2, SW40.2, SW48.2, SW56.2, U9.15 (S4)
unnamed: SW9.2, SW17.2, SW25.2, SW33.2, SW41.2, SW49.2, SW57.2, U9.16 (S5)
unnamed: SW21.1, SW22.1, SW23.1, SW24.1, SW25.1, SW26.1, SW27.1, SW28.1, U9.3 (D3)
unnamed: SW29.1, SW30.1, SW31.1, SW32.1, SW33.1, SW34.1, SW35.1, SW36.1, U9.4 (D4)
unnamed: SW37.1, SW38.1, SW39.1, SW40.1, SW41.1, SW42.1, SW43.1, SW44.1, U9.5 (D5)
unnamed: SW45.1, SW46.1, SW47.1, SW48.1, SW49.1, SW50.1, SW51.1, SW52.1, U9.6 (D6)
unnamed: SW53.1, SW54.1, SW55.1, SW56.1, SW57.1, SW58.1, SW59.1, SW60.1, U9.8 (D8)

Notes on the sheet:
This work is licensed under the Creative Commons Attribution-ShareAlike 4.0 International License. To view a copy of this license, visit http://creativecommons.org/licenses/by-sa/4.0/ or send a letter to Creative Commons, PO Box 1866, Mountain View, CA 94042, USA.
COMIX-35
Keyboard Section By @TubeTimeUS

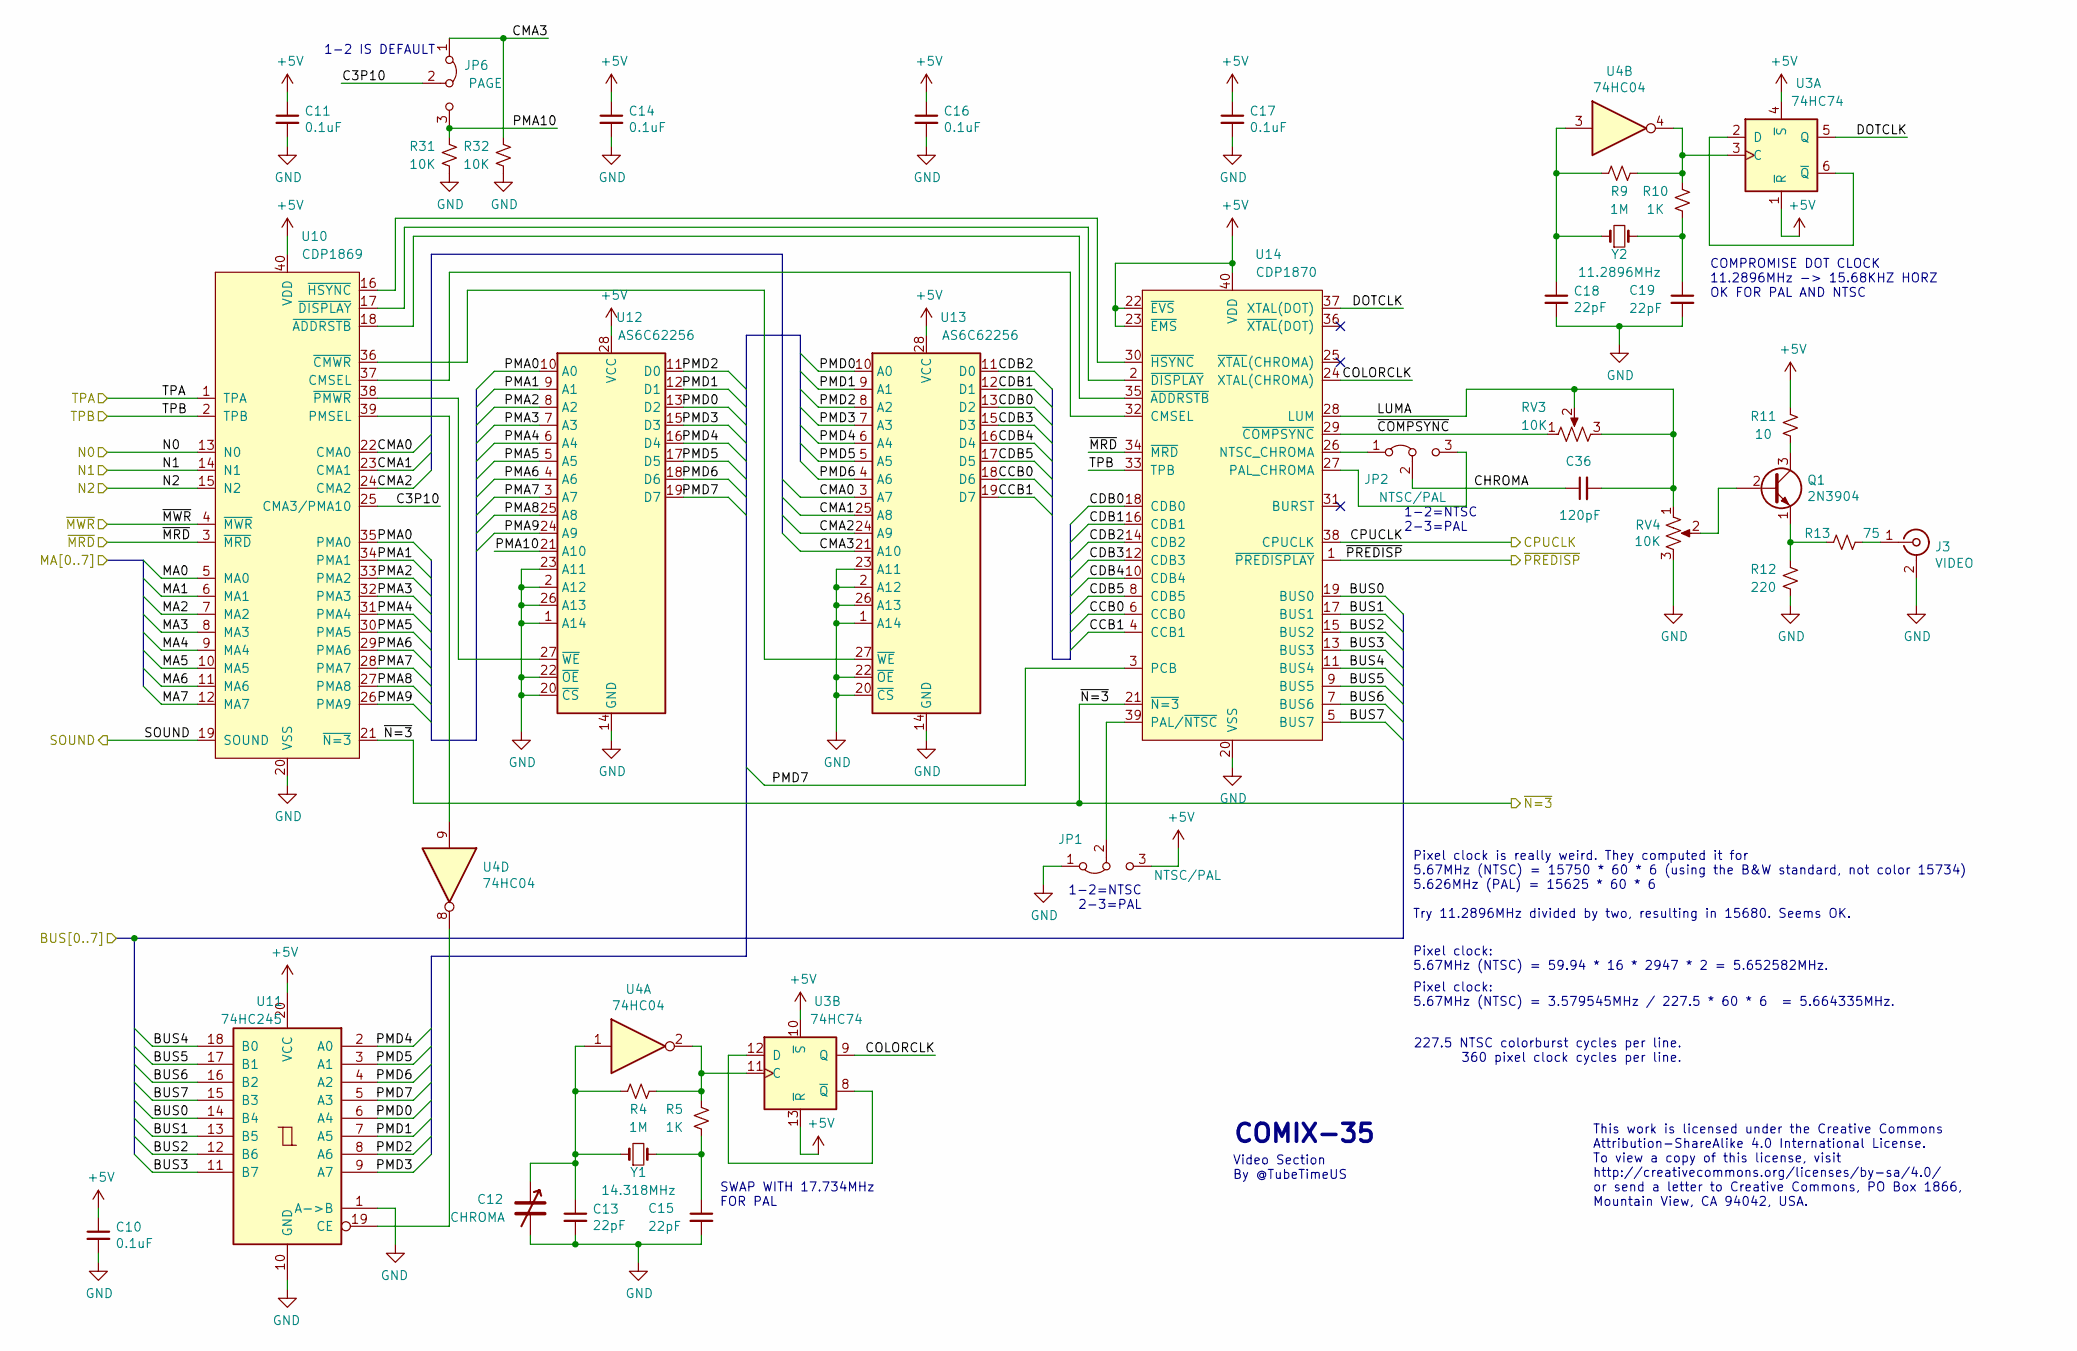
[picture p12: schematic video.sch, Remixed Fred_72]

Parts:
C10, C11, C14, C16, C17: 0.1uF; CAPAC200; Mouser 581-SA105E104M
C12: CHROMA; EW_GKG; Digikey 2447-GKG30015-ND
C13, C15, C18, C19: 22pF; CAPAC200; Mouser 810-FG28C0G2A220JNT0
C36: 120pF; CAPAC200; Mouser 810-FG28C0G1H121JNT6
J3: VIDEO; RCA_metal_Horizontal_L5mm; Mouser 161-0360-E
JP1, JP2: NTSC/PAL; Pin_Header_Straight_1x03_Pitch2.54mm
JP6: PAGE; Pin_Header_Straight_1x03_Pitch2.54mm
Q1: 2N3904; TO92-IL; Mouser 512-2N3904BU
R4, R9: 1M; RESA500; Mouser 603-CFR-25JR-521M
R5, R10: 1K; RESA500; Mouser 603-CFR-25JR-521K
R11: 10; RESA500; Mouser 603-CFR-25JR-5210R
R12: 220; RESA500; Mouser 603-CFR-25JR-52220R
R13: 75; RESA500; Mouser 603-CFR-25JR-5275R
R31, R32: 10K; RESA500; Mouser 603-CFR-25JB-52-10K
RV3, RV4: 10K; Potentiometer_Bourns_3339P_Vertical_HandSoldering; Mouser 531-PT10H-10K-S
U3: 74HC74; DIP-14_W7.62mm; Mouser 595-SN74HC74N
U4: 74HC04; DIP-14_W7.62mm; Mouser 595-SN74HC04N
U10: CDP1869; DIP-40_W15.24mm
U11: 74HC245; DIP-20_W7.62mm; Mouser 595-SN74HC245N
U12, U13: AS6C62256; DIP-28_W15.24mm; Mouser 913-AS6C62256-55PCN
U14: CDP1870; DIP-40_W15.24mm
Y1: 14.318MHz; Crystal_HC49-4H_Vertical; Mouser 815-ABL-14.31818B2
Y2: 11.2896MHz; Crystal_HC49-4H_Vertical; Mouser 815-ABL-11.2896-B4Y

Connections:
+5V: C10.1, C11.1, C14.1, C16.1, C17.1, JP1.3 (B), R11.1, U3.1 (~R), U3.4 (~S), U3.10 (~S), U3.13 (~R), U10.40 (VDD), U11.20 (VCC), U12.28 (VCC), U13.28 (VCC), U14.22 (~EVS), U14.23 (~EMS), U14.40 (VDD); also elsewhere on the board
/BUS0: U11.14 (B4), U14.19 (BUS0); also elsewhere on the board
/BUS1: U11.13 (B5), U14.17 (BUS1); also elsewhere on the board
/BUS2: U11.12 (B6), U14.15 (BUS2); also elsewhere on the board
/BUS3: U11.11 (B7), U14.13 (BUS3); also elsewhere on the board
/BUS4: U11.18 (B0), U14.11 (BUS4); also elsewhere on the board
/BUS5: U11.17 (B1), U14.9 (BUS5); also elsewhere on the board
/BUS6: U11.16 (B2), U14.7 (BUS6); also elsewhere on the board
/BUS7: U11.15 (B3), U14.5 (BUS7); also elsewhere on the board
/CPUCLK: U14.38 (CPUCLK); also elsewhere on the board
/MA0: U10.5 (MA0); also elsewhere on the board
/MA1: U10.6 (MA1); also elsewhere on the board
/MA2: U10.7 (MA2); also elsewhere on the board
/MA3: U10.8 (MA3); also elsewhere on the board
/MA4: U10.9 (MA4); also elsewhere on the board
/MA5: U10.10 (MA5); also elsewhere on the board
/MA6: U10.11 (MA6); also elsewhere on the board
/MA7: U10.12 (MA7); also elsewhere on the board
/N0: U10.13 (N0); also elsewhere on the board
/N1: U10.14 (N1); also elsewhere on the board
/N2: U10.15 (N2); also elsewhere on the board
/TPA: U10.1 (TPA); also elsewhere on the board
/TPB: U10.2 (TPB), U14.33 (TPB); also elsewhere on the board
/cassetteaudio/SOUND: U10.19 (SOUND); also elsewhere on the board
/keyboard/~N=3: U10.21 (~N=3), U14.21 (~N=3); also elsewhere on the board
/video/C3P10: JP6.2 (C), U10.25 (CMA3/PMA10)
/video/CCB0: U13.18 (D6), U14.6 (CCB0)
/video/CCB1: U13.19 (D7), U14.4 (CCB1)
/video/CDB0: U13.13 (D2), U14.18 (CDB0)
/video/CDB1: U13.12 (D1), U14.16 (CDB1)
/video/CDB2: U13.11 (D0), U14.14 (CDB2)
/video/CDB3: U13.15 (D3), U14.12 (CDB3)
/video/CDB4: U13.16 (D4), U14.10 (CDB4)
/video/CDB5: U13.17 (D5), U14.8 (CDB5)
/video/CHROMA: C36.1, JP2.2 (C)
/video/CMA0: U10.22 (CMA0), U13.3 (A7)
/video/CMA1: U10.23 (CMA1), U13.25 (A8)
/video/CMA2: U10.24 (CMA2), U13.24 (A9)
/video/CMA3: JP6.1 (A), R32.1, U13.21 (A10)
/video/COLORCLK: U3.9 (Q), U14.24 (XTAL(CHROMA))
/video/DOTCLK: U3.5 (Q), U14.37 (XTAL(DOT))
/video/LUMA: C36.2, RV3.2, RV3.3, RV4.1, U14.28 (LUM)
/video/PMA0: U10.35 (PMA0), U12.10 (A0)
/video/PMA1: U10.34 (PMA1), U12.9 (A1)
/video/PMA2: U10.33 (PMA2), U12.8 (A2)
/video/PMA3: U10.32 (PMA3), U12.7 (A3)
/video/PMA4: U10.31 (PMA4), U12.6 (A4)
/video/PMA5: U10.30 (PMA5), U12.5 (A5)
/video/PMA6: U10.29 (PMA6), U12.4 (A6)
/video/PMA7: U10.28 (PMA7), U12.3 (A7)
/video/PMA8: U10.27 (PMA8), U12.25 (A8)
/video/PMA9: U10.26 (PMA9), U12.24 (A9)
/video/PMA10: JP6.3 (B), R31.1, U12.21 (A10)
/video/PMD0: U11.6 (A4), U12.13 (D2), U13.10 (A0)
/video/PMD1: U11.7 (A5), U12.12 (D1), U13.9 (A1)
/video/PMD2: U11.8 (A6), U12.11 (D0), U13.8 (A2)
/video/PMD3: U11.9 (A7), U12.15 (D3), U13.7 (A3)
/video/PMD4: U11.2 (A0), U12.16 (D4), U13.6 (A4)
/video/PMD5: U11.3 (A1), U12.17 (D5), U13.5 (A5)
/video/PMD6: U11.4 (A2), U12.18 (D6), U13.4 (A6)
/video/PMD7: U11.5 (A3), U12.19 (D7), U14.3 (PCB)
/video/~COMPSYNC: RV3.1, U14.29 (~COMPSYNC)
/~MRD: U10.3 (~MRD), U14.34 (~MRD); also elsewhere on the board
/~MWR: U10.4 (~MWR); also elsewhere on the board
/~PREDISP: U14.1 (~PREDISPLAY); also elsewhere on the board
GND: C10.2, C11.2, C12.2, C13.2, C14.2, C15.2, C16.2, C17.2, C18.2, C19.2, J3.2 (Ext), JP1.1 (A), R12.2, R31.2, R32.2, RV4.3, U10.20 (VSS), U11.1 (A->B), U11.10 (GND), U12.1 (A14), U12.2 (A12), U12.14 (GND), U12.20 (~CS), U12.22 (~OE), U12.23 (A11), U12.26 (A13), U13.1 (A14), U13.2 (A12), U13.14 (GND), U13.20 (~CS), U13.22 (~OE), U13.23 (A11), U13.26 (A13), U14.20 (VSS); also elsewhere on the board
unnamed: C12.1, C13.1, R4.1, U4.1, Y1.1
unnamed: C15.1, R5.2, Y1.2
unnamed: C18.1, R9.1, U4.3, Y2.1
unnamed: C19.1, R10.2, Y2.2
unnamed: J3.1 (In), R13.2
unnamed: JP1.2 (C), U14.39 (PAL/~NTSC)
unnamed: JP2.1 (A), U14.26 (NTSC_CHROMA)
unnamed: JP2.3 (B), U14.27 (PAL_CHROMA)
unnamed: Q1.1 (E), R12.1, R13.1
unnamed: Q1.2 (B), RV4.2
unnamed: Q1.3 (C), R11.2
unnamed: R4.2, R5.1, U3.11 (C), U4.2
unnamed: R9.2, R10.1, U3.3 (C), U4.4
unnamed: U3.2 (D), U3.6 (~Q)
unnamed: U3.8 (~Q), U3.12 (D)
unnamed: U10.16 (~HSYNC), U14.30 (~HSYNC)
unnamed: U10.17 (~DISPLAY), U14.2 (~DISPLAY)
unnamed: U10.18 (~ADDRSTB), U14.35 (~ADDRSTB)
unnamed: U10.36 (~CMWR), U13.27 (~WE)
unnamed: U10.37 (CMSEL), U14.32 (CMSEL)
unnamed: U10.38 (~PMWR), U12.27 (~WE)
unnamed: U4.9, U10.39 (PMSEL)
unnamed: U4.8, U11.19 (CE)

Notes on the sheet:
COMPROMISE DOT CLOCK 11.2896MHz -> 15.68KHZ HORZ OK FOR PAL AND NTSC
SWAP WITH 17.734MHz FOR PAL
1-2=NTSC 2-3=PAL
Pixel clock is really weird. They computed it for 5.67MHz (NTSC) = 15750 * 60 * 6 (using the B&W standard, not color 15734) 5.626MHz (PAL) = 15625 * 60 * 6 Try 11.2896MHz divided by two, resulting in 15680. Seems OK.
Pixel clock: 5.67MHz (NTSC) = 59.94 * 16 * 2947 * 2 = 5.652582MHz.
Pixel clock: 5.67MHz (NTSC) = 3.579545MHz / 227.5 * 60 * 6 = 5.664335MHz.
227.5 NTSC colorburst cycles per line. 360 pixel clock cycles per line.
1-2 IS DEFAULT
This work is licensed under the Creative Commons Attribution-ShareAlike 4.0 International License. To view a copy of this license, visit http://creativecommons.org/licenses/by-sa/4.0/ or send a letter to Creative Commons, PO Box 1866, Mountain View, CA 94042, USA.
COMIX-35
Video Section By @TubeTimeUS

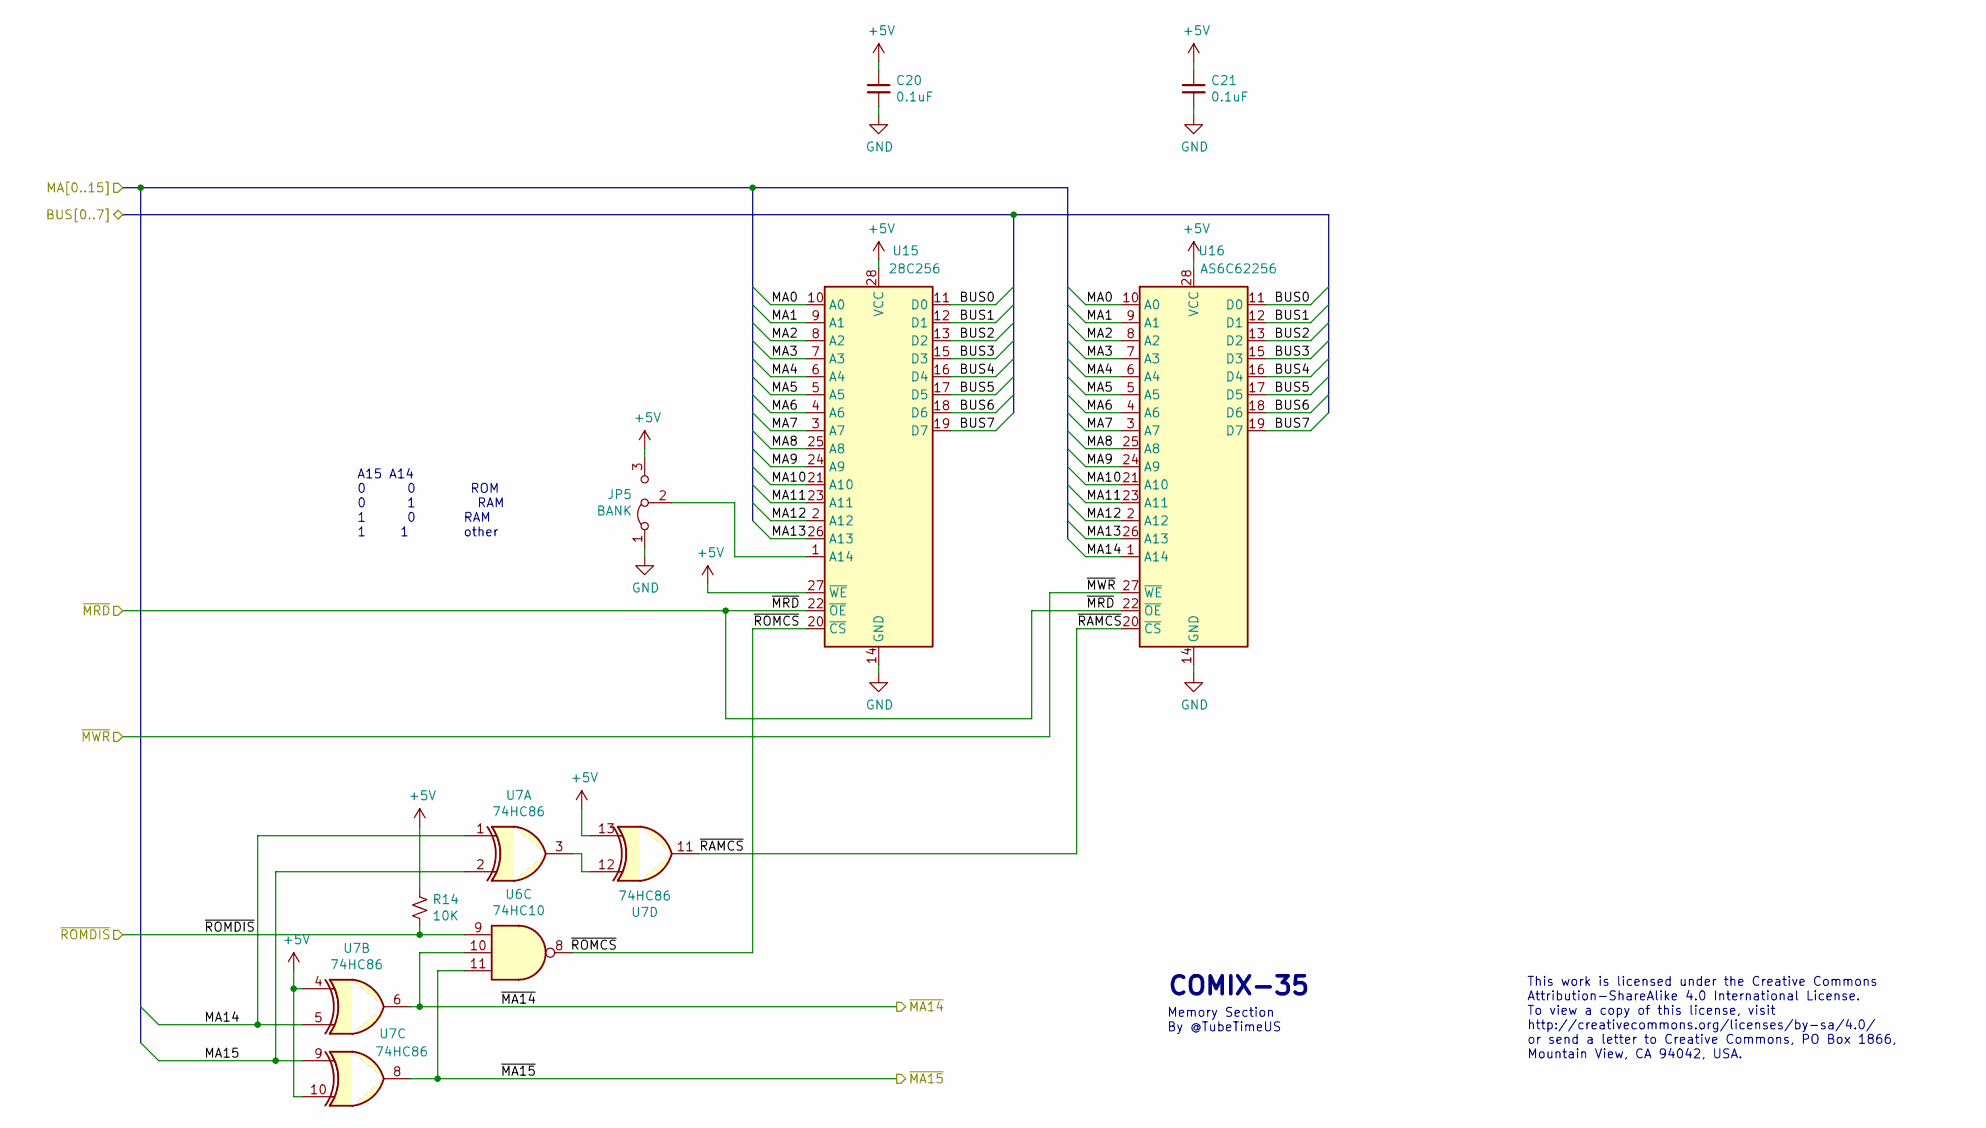
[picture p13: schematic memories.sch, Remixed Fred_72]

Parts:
C20, C21: 0.1uF; CAPAC200; Mouser 581-SA105E104M
JP5: BANK; Pin_Header_Straight_1x03_Pitch2.54mm
R14: 10K; RESA500; Mouser 603-CFR-25JB-52-10K
U6: 74HC10; DIP-14_W7.62mm; Mouser 595-SN74HC10N
U7: 74HC86; DIP-14_W7.62mm; Mouser 595-SN74HC86N
U15: 28C256; DIP-28_W15.24mm; Mouser 556-AT28C25615PU
U16: AS6C62256; DIP-28_W15.24mm; Mouser 913-AS6C62256-55PCN

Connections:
+5V: C20.1, C21.1, JP5.3 (B), R14.2, U7.4, U7.10, U7.13, U15.27 (~WE), U15.28 (VCC), U16.28 (VCC); also elsewhere on the board
/BUS0: U15.11 (D0), U16.11 (D0); also elsewhere on the board
/BUS1: U15.12 (D1), U16.12 (D1); also elsewhere on the board
/BUS2: U15.13 (D2), U16.13 (D2); also elsewhere on the board
/BUS3: U15.15 (D3), U16.15 (D3); also elsewhere on the board
/BUS4: U15.16 (D4), U16.16 (D4); also elsewhere on the board
/BUS5: U15.17 (D5), U16.17 (D5); also elsewhere on the board
/BUS6: U15.18 (D6), U16.18 (D6); also elsewhere on the board
/BUS7: U15.19 (D7), U16.19 (D7); also elsewhere on the board
/MA0: U15.10 (A0), U16.10 (A0); also elsewhere on the board
/MA1: U15.9 (A1), U16.9 (A1); also elsewhere on the board
/MA2: U15.8 (A2), U16.8 (A2); also elsewhere on the board
/MA3: U15.7 (A3), U16.7 (A3); also elsewhere on the board
/MA4: U15.6 (A4), U16.6 (A4); also elsewhere on the board
/MA5: U15.5 (A5), U16.5 (A5); also elsewhere on the board
/MA6: U15.4 (A6), U16.4 (A6); also elsewhere on the board
/MA7: U15.3 (A7), U16.3 (A7); also elsewhere on the board
/MA14: U7.1, U7.5, U16.1 (A14); also elsewhere on the board
/cpu/MA8: U15.25 (A8), U16.25 (A8); also elsewhere on the board
/cpu/MA9: U15.24 (A9), U16.24 (A9); also elsewhere on the board
/cpu/MA10: U15.21 (A10), U16.21 (A10); also elsewhere on the board
/cpu/MA11: U15.23 (A11), U16.23 (A11); also elsewhere on the board
/cpu/MA12: U15.2 (A12), U16.2 (A12); also elsewhere on the board
/cpu/MA13: U15.26 (A13), U16.26 (A13); also elsewhere on the board
/cpu/MA15: U7.2, U7.9; also elsewhere on the board
/memories/~RAMCS: U7.11, U16.20 (~CS)
/memories/~ROMCS: U6.8, U15.20 (~CS)
/~MA14: U6.10, U7.6; also elsewhere on the board
/~MA15: U6.11, U7.8; also elsewhere on the board
/~MRD: U15.22 (~OE), U16.22 (~OE); also elsewhere on the board
/~MWR: U16.27 (~WE); also elsewhere on the board
/~ROMDIS: R14.1, U6.9; also elsewhere on the board
GND: C20.2, C21.2, JP5.1 (A), U15.14 (GND), U16.14 (GND); also elsewhere on the board
unnamed: JP5.2 (C), U15.1 (A14)
unnamed: U7.3, U7.12

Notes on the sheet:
A15 A14 0 0 ROM 0 1 RAM 1 0 RAM 1 1 other
This work is licensed under the Creative Commons Attribution-ShareAlike 4.0 International License. To view a copy of this license, visit http://creativecommons.org/licenses/by-sa/4.0/ or send a letter to Creative Commons, PO Box 1866, Mountain View, CA 94042, USA.
COMIX-35
Memory Section By @TubeTimeUS

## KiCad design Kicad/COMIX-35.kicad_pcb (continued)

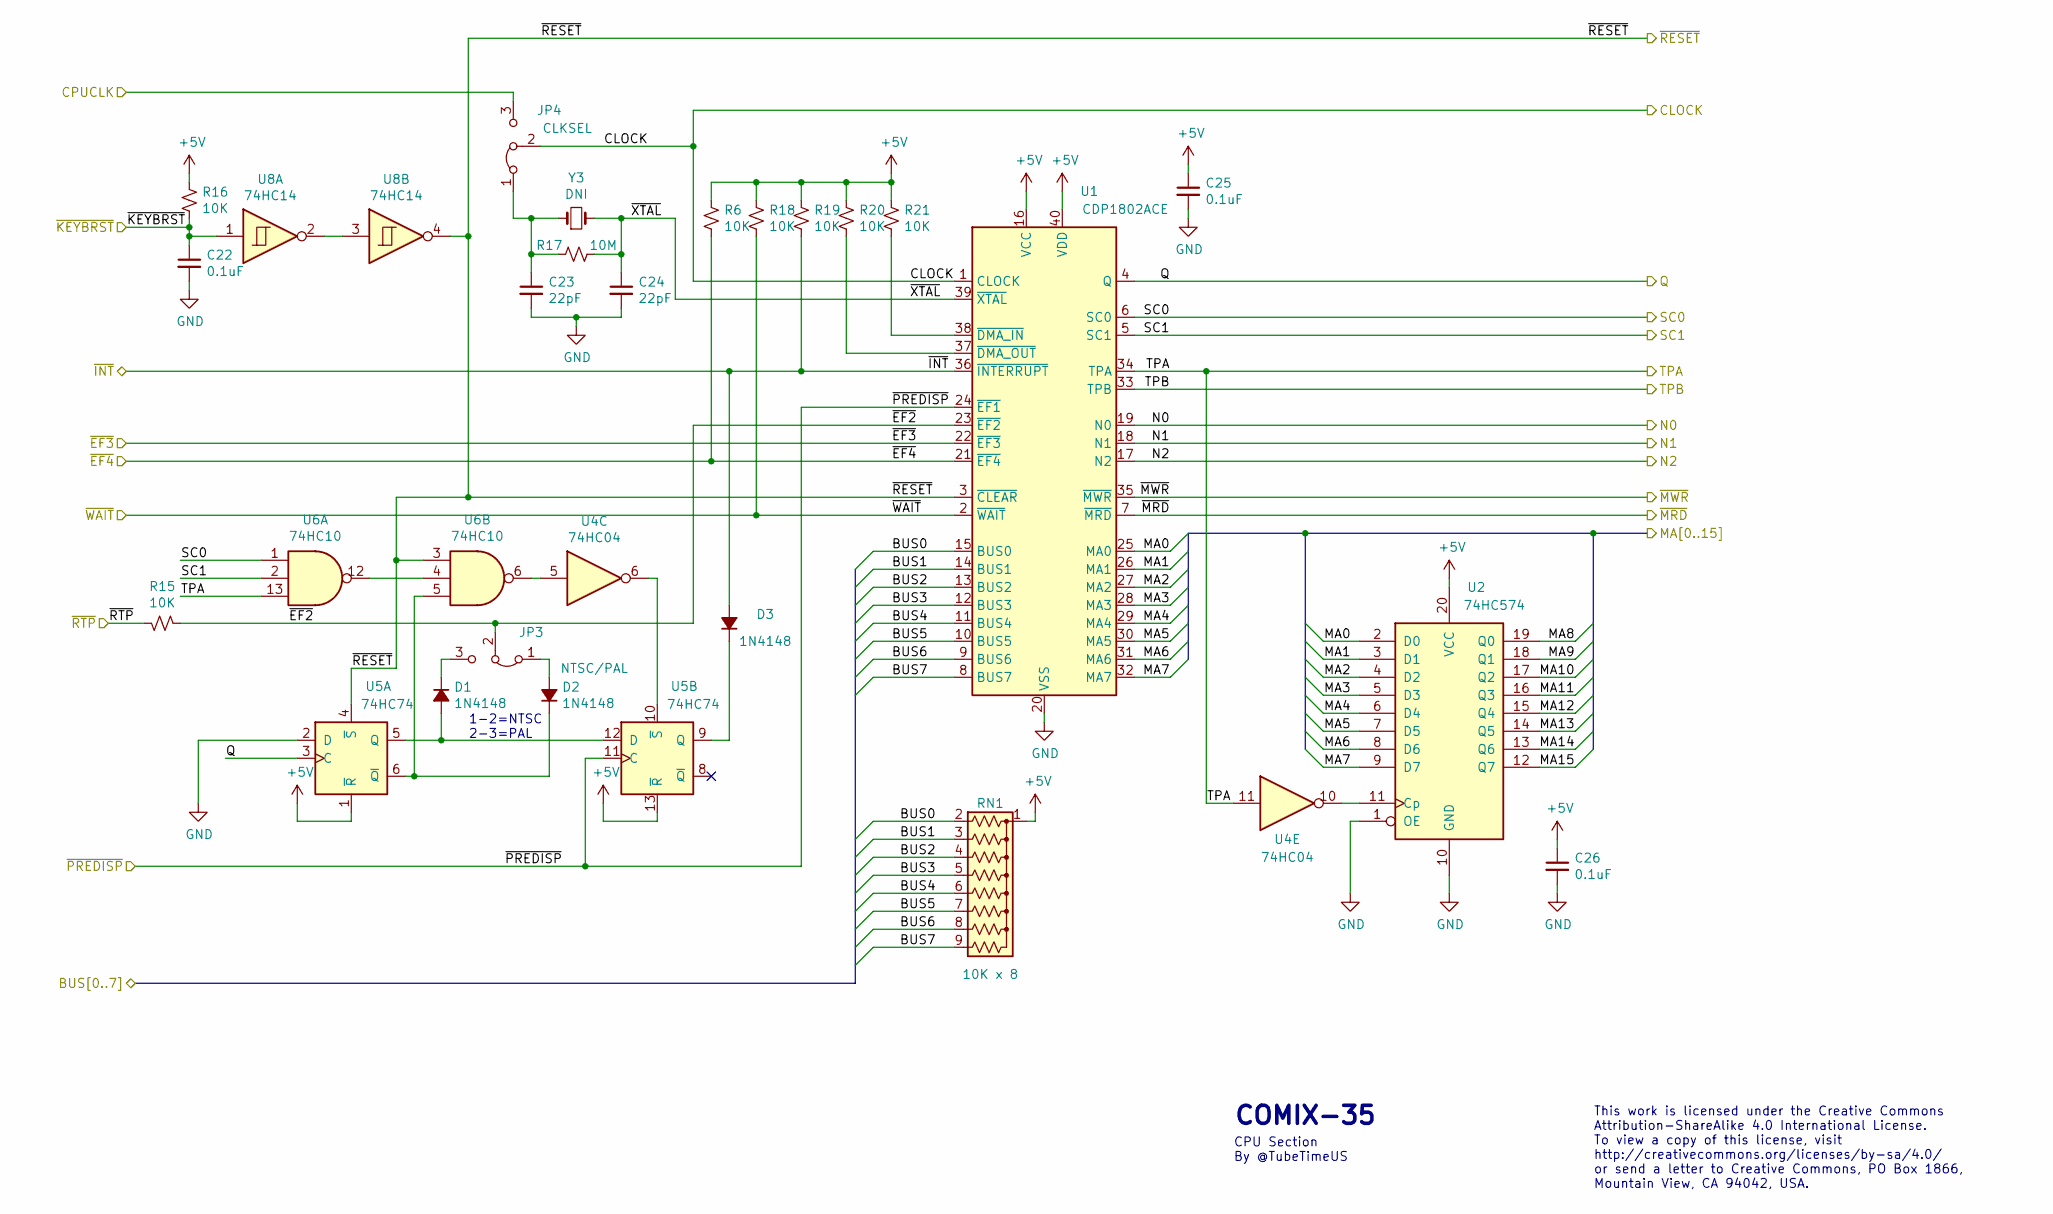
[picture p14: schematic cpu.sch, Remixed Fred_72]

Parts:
C22, C25, C26: 0.1uF; CAPAC200; Mouser 581-SA105E104M
C23, C24: 22pF; CAPAC200; Mouser 810-FG28C0G2A220JNT0
D1, D2, D3: 1N4148; DIOA500; Mouser 512-1N4148
JP3: NTSC/PAL; Pin_Header_Straight_1x03_Pitch2.54mm
JP4: CLKSEL; Pin_Header_Straight_1x03_Pitch2.54mm
R6, R15, R16, R18, R19, R20, R21: 10K; RESA500; Mouser 603-CFR-25JB-52-10K
R17: 10M; RESA500; Mouser 603-CFR-25JT-52-10M
RN1: 10K x 8; Pin_Header_Straight_1x09_Pitch2.54mm; Mouser 652-4609X-1LF-10K
U1: CDP1802ACE; DIP-40_W15.24mm
U2: 74HC574; DIP-20_W7.62mm; Mouser 595-SN74HC574N
U4: 74HC04; DIP-14_W7.62mm; Mouser 595-SN74HC04N
U5: 74HC74; DIP-14_W7.62mm; Mouser 595-SN74HC74N
U6: 74HC10; DIP-14_W7.62mm; Mouser 595-SN74HC10N
U8: 74HC14; DIP-14_W7.62mm; Mouser 595-SN74HC14N
Y3: DNI; Crystal_HC49-4H_Vertical; Mouser DNI

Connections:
+5V: C25.1, C26.1, R6.2, R16.2, R18.2, R19.2, R20.2, R21.2, RN1.1 (common), U1.16 (VCC), U1.40 (VDD), U2.20 (VCC), U5.1 (~R), U5.13 (~R); also elsewhere on the board
/BUS0: RN1.2 (R1), U1.15 (BUS0); also elsewhere on the board
/BUS1: RN1.3 (R2), U1.14 (BUS1); also elsewhere on the board
/BUS2: RN1.4 (R3), U1.13 (BUS2); also elsewhere on the board
/BUS3: RN1.5 (R4), U1.12 (BUS3); also elsewhere on the board
/BUS4: RN1.6 (R5), U1.11 (BUS4); also elsewhere on the board
/BUS5: RN1.7 (R6), U1.10 (BUS5); also elsewhere on the board
/BUS6: RN1.8 (R7), U1.9 (BUS6); also elsewhere on the board
/BUS7: RN1.9 (R8), U1.8 (BUS7); also elsewhere on the board
/CLOCK: JP4.2 (C), U1.1 (CLOCK); also elsewhere on the board
/CPUCLK: JP4.3 (B); also elsewhere on the board
/MA0: U1.25 (MA0), U2.2 (D0); also elsewhere on the board
/MA1: U1.26 (MA1), U2.3 (D1); also elsewhere on the board
/MA2: U1.27 (MA2), U2.4 (D2); also elsewhere on the board
/MA3: U1.28 (MA3), U2.5 (D3); also elsewhere on the board
/MA4: U1.29 (MA4), U2.6 (D4); also elsewhere on the board
/MA5: U1.30 (MA5), U2.7 (D5); also elsewhere on the board
/MA6: U1.31 (MA6), U2.8 (D6); also elsewhere on the board
/MA7: U1.32 (MA7), U2.9 (D7); also elsewhere on the board
/MA14: U2.13 (Q6); also elsewhere on the board
/N0: U1.19 (N0); also elsewhere on the board
/N1: U1.18 (N1); also elsewhere on the board
/N2: U1.17 (N2); also elsewhere on the board
/Q: U1.4 (Q), U5.3 (C); also elsewhere on the board
/SC0: U1.6 (SC0), U6.1; also elsewhere on the board
/SC1: U1.5 (SC1), U6.2; also elsewhere on the board
/TPA: U1.34 (TPA), U4.11, U6.13; also elsewhere on the board
/TPB: U1.33 (TPB); also elsewhere on the board
/cpu/MA8: U2.19 (Q0); also elsewhere on the board
/cpu/MA9: U2.18 (Q1); also elsewhere on the board
/cpu/MA10: U2.17 (Q2); also elsewhere on the board
/cpu/MA11: U2.16 (Q3); also elsewhere on the board
/cpu/MA12: U2.15 (Q4); also elsewhere on the board
/cpu/MA13: U2.14 (Q5); also elsewhere on the board
/cpu/MA15: U2.12 (Q7); also elsewhere on the board
/cpu/~EF2: JP3.2 (C), R15.2, U1.23 (~EF2)
/cpu/~XTAL: C24.1, R17.2, U1.39 (~XTAL), Y3.2
/~EF3: U1.22 (~EF3); also elsewhere on the board
/~EF4: R6.1, U1.21 (~EF4); also elsewhere on the board
/~INT: D3.2 (A), R19.1, U1.36 (~INTERRUPT); also elsewhere on the board
/~KBDRST: C22.1, R16.1, U8.1; also elsewhere on the board
/~MRD: U1.7 (~MRD); also elsewhere on the board
/~MWR: U1.35 (~MWR); also elsewhere on the board
/~PREDISP: U1.24 (~EF1), U5.11 (C); also elsewhere on the board
/~RESET: U1.3 (~CLEAR), U5.4 (~S), U6.3, U8.4; also elsewhere on the board
/~RTP: R15.1; also elsewhere on the board
/~WAIT: R18.1, U1.2 (~WAIT); also elsewhere on the board
GND: C22.2, C23.2, C24.2, C25.2, C26.2, U1.20 (VSS), U2.1 (OE), U2.10 (GND), U5.2 (D); also elsewhere on the board
unnamed: C23.1, JP4.1 (A), R17.1, Y3.1
unnamed: D1.1 (K), JP3.3 (B)
unnamed: D1.2 (A), U5.5 (Q), U5.12 (D)
unnamed: D2.1 (K), U5.6 (~Q), U6.5
unnamed: D2.2 (A), JP3.1 (A)
unnamed: D3.1 (K), U5.9 (Q)
unnamed: R20.1, U1.37 (~DMA_OUT)
unnamed: R21.1, U1.38 (~DMA_IN)
unnamed: U2.11 (Cp), U4.10
unnamed: U4.5, U6.6
unnamed: U4.6, U5.10 (~S)
unnamed: U6.4, U6.12
unnamed: U8.2, U8.3

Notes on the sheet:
1-2=NTSC 2-3=PAL
This work is licensed under the Creative Commons Attribution-ShareAlike 4.0 International License. To view a copy of this license, visit http://creativecommons.org/licenses/by-sa/4.0/ or send a letter to Creative Commons, PO Box 1866, Mountain View, CA 94042, USA.
COMIX-35
CPU Section By @TubeTimeUS

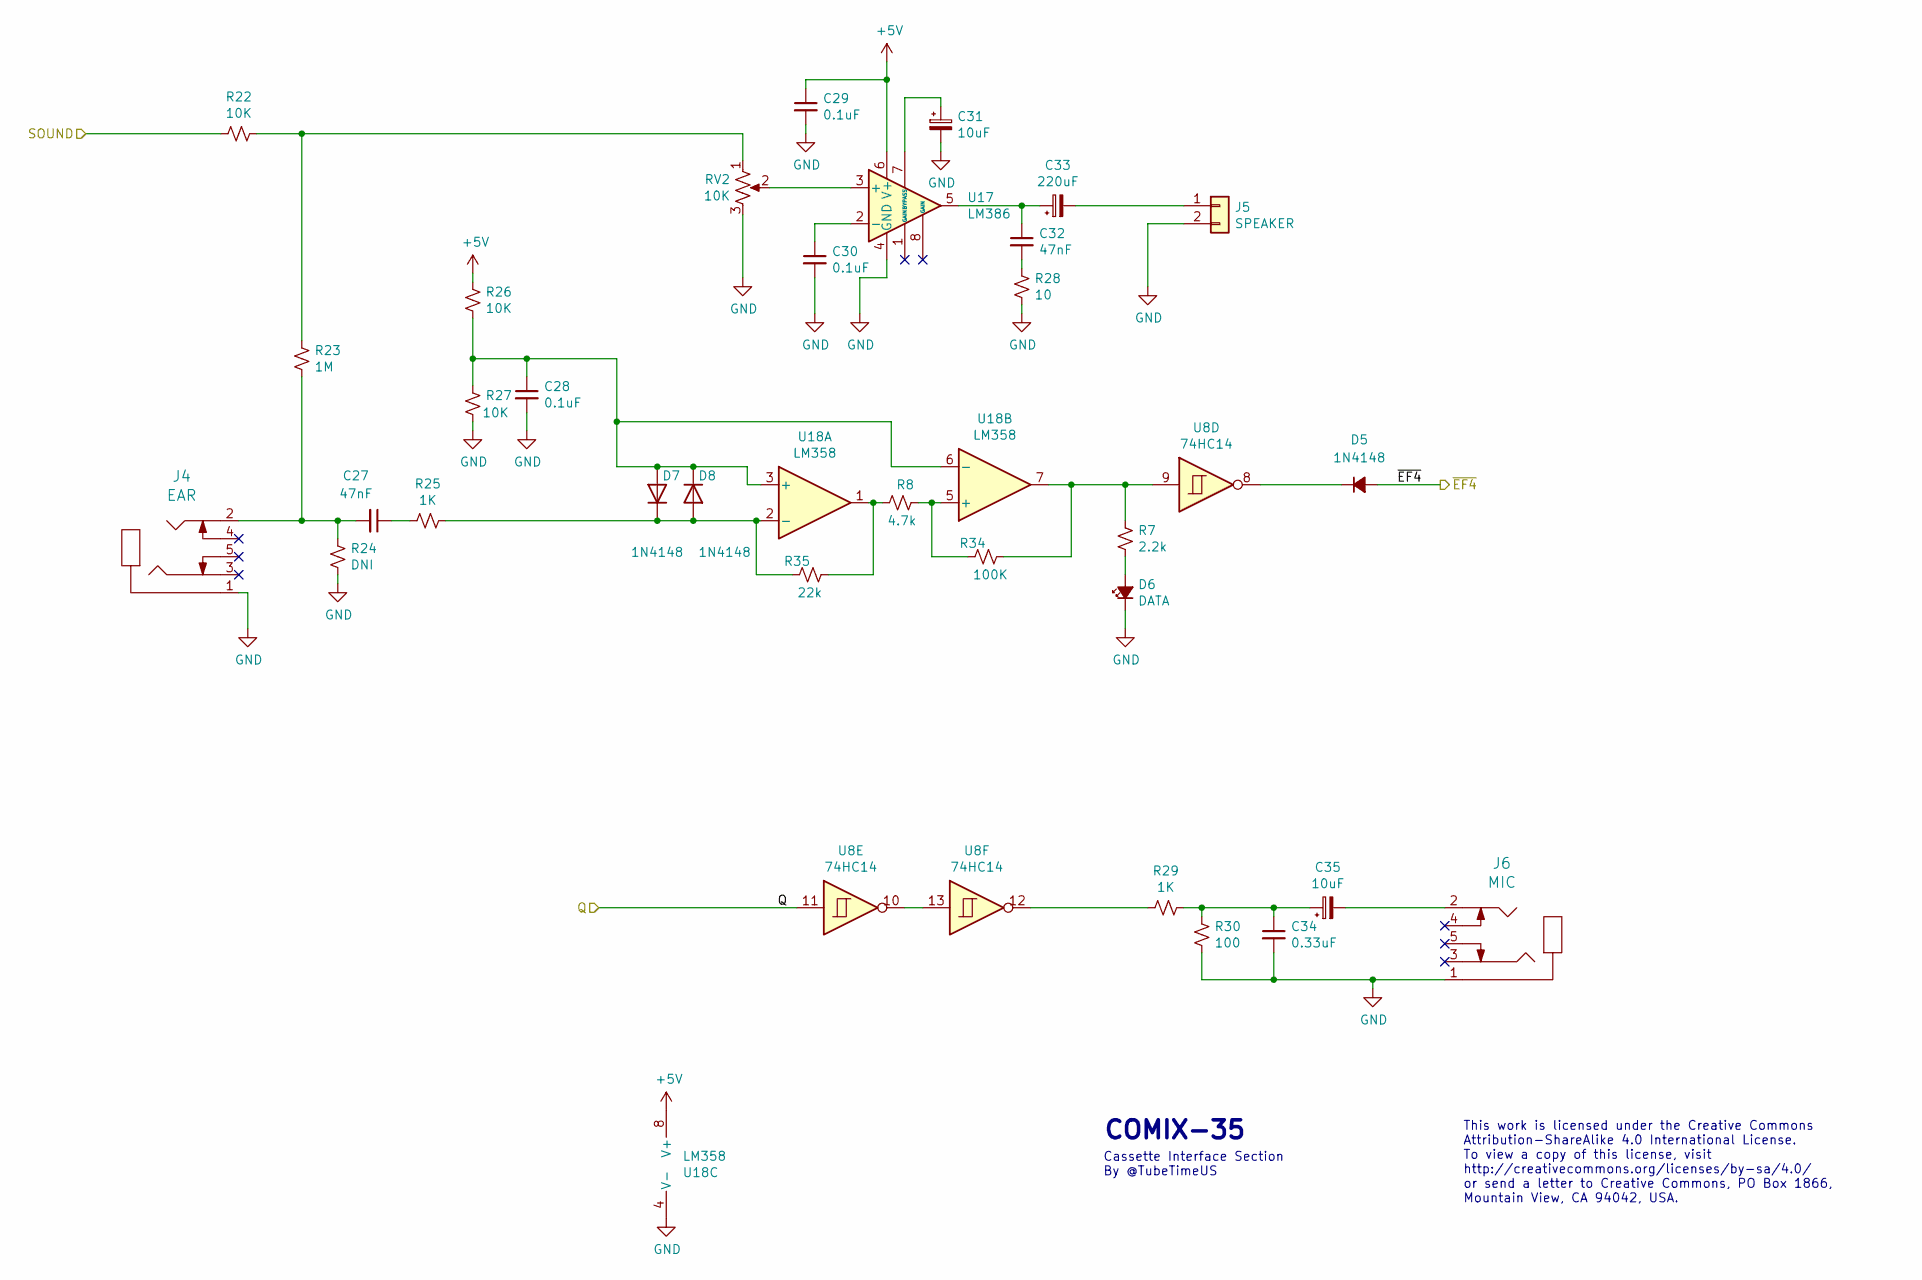
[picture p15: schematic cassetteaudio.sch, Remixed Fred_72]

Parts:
C27: 47nF; CAPAC200; Mouser 810-FG24X7R1H334KNT6
C28: 0.1uF; CAPAC200; Mouser 810-FG28X7R1H102KNT6
C29, C30: 0.1uF; CAPAC200; Mouser 581-SA105E104M
C31, C35: 10uF; CAPAE250P630X1100; Mouser 667-ECA-1CM100I
C32: 47nF; CAPAC200; Mouser 810-FA28X7R1H47300
C33: 220uF; CAPAE250P630X1100; Mouser 647-UVY1E221MED1TD
C34: 0.33uF; CAPAC200; Mouser 810-FG28X7R1H334KRT0
D5: 1N4148; DIOA500; Mouser 512-1N4148
D6: DATA; LED_D5.0mm; Mouser 859-LTL-4213
D7, D8: 1N4148; D_DO-35_SOD27_P7.62mm_Horizontal
J4: EAR; CUI_SJ1-353XN; Mouser 490-SJ1-3533NG
J5: SPEAKER; Pin_Header_Straight_1x02_Pitch2.54mm
J6: MIC; CUI_SJ1-353XN; Mouser 490-SJ1-3533NG
R7: 2.2k; RESA500; Mouser 603-CFR-25JR-52220R
R8: 4.7k; RESA500; Mouser 603-CFR-25JB-52-10K
R22, R26, R27: 10K; RESA500; Mouser 603-CFR-25JB-52-10K
R23: 1M; RESA500; Mouser 603-CFR-25JR-521M
R24: DNI; RESA500; Mouser DNI
R25, R29: 1K; RESA500; Mouser 603-CFR-25JR-521K
R28: 10; RESA500; Mouser 603-CFR-25JR-5210R
R30: 100; RESA500; Mouser 603-CFR-25JR-52100R
R34: 100K; RESA500; Mouser 603-CFR-25JB-52-10K
R35: 22k; RESA500; Mouser 603-CFR-25JB-52-10K
RV2: 10K; POT_plat_PCB; Mouser 531-PT10H-10K-S
U8: 74HC14; DIP-14_W7.62mm; Mouser 595-SN74HC14N
U17: LM386; DIP-8_W7.62mm; Mouser 926-LM386N-4/NOPB
U18: LM358; DIP-8_W7.62mm

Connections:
+5V: C29.1, R26.1, U17.6 (V+), U18.8 (V+); also elsewhere on the board
/Q: U8.11; also elsewhere on the board
/cassetteaudio/SOUND: R22.2; also elsewhere on the board
/~EF4: D5.2 (A); also elsewhere on the board
GND: C28.2, C29.2, C30.2, C31.2, C34.2, D6.1 (K), J4.1, J5.2, J6.1, R24.1, R27.2, R28.2, R30.2, RV2.3, U17.4 (GND), U18.4 (V-); also elsewhere on the board
unnamed: C27.1, R25.2
unnamed: C27.2, J4.2, R23.2, R24.2
unnamed: C28.1, D7.2 (A), D8.1 (K), R26.2, R27.1, U18.3 (+), U18.6 (-)
unnamed: C30.1, U17.2 (-)
unnamed: C31.1, U17.7 (BYPASS)
unnamed: C32.1, C33.1, U17.5
unnamed: C32.2, R28.1
unnamed: C33.2, J5.1
unnamed: C34.1, C35.1, R29.1, R30.1
unnamed: C35.2, J6.2
unnamed: D5.1 (K), U8.8
unnamed: D6.2 (A), R7.1
unnamed: D7.1 (K), D8.2 (A), R25.1, R35.2, U18.2 (-)
unnamed: R22.1, R23.1, RV2.1
unnamed: R29.2, U8.12
unnamed: R7.2, R34.1, U8.9, U18.7
unnamed: R8.1, R34.2, U18.5 (+)
unnamed: R8.2, R35.1, U18.1
unnamed: RV2.2, U17.3 (+)
unnamed: U8.10, U8.13

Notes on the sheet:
This work is licensed under the Creative Commons Attribution-ShareAlike 4.0 International License. To view a copy of this license, visit http://creativecommons.org/licenses/by-sa/4.0/ or send a letter to Creative Commons, PO Box 1866, Mountain View, CA 94042, USA.
COMIX-35
Cassette Interface Section By @TubeTimeUS

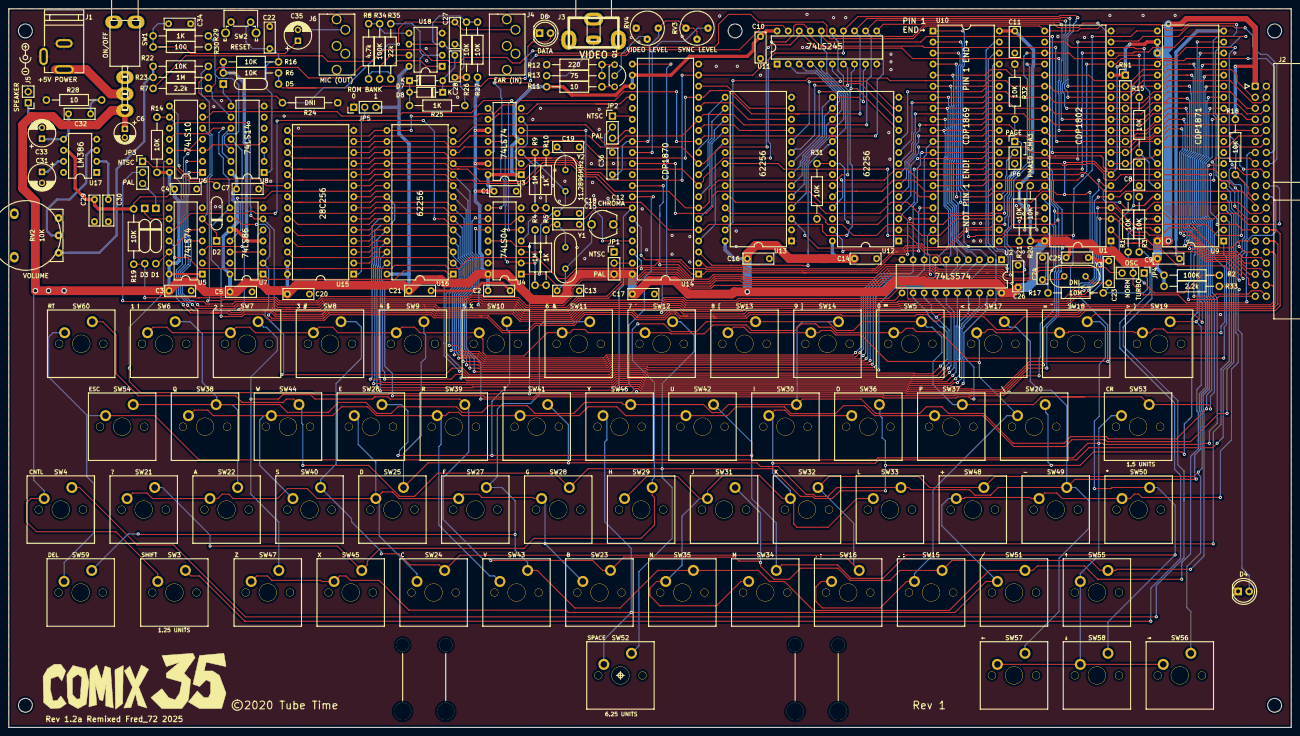
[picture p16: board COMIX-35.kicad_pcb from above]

Board: 2 copper layers, 294.6 x 165.1 mm, 183 parts (0 on the bottom side), 170 nets.

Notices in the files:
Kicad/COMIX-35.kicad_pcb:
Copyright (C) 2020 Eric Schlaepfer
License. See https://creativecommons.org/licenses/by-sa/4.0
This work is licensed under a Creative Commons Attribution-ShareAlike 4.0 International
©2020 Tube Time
